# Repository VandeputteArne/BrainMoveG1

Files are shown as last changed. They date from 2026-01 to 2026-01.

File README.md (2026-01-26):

# BrainMoveG1

Een interactief cognitief en motorisch trainingssysteem met fysieke aanraakgevoelige gekleurde potten en boeiende browsergebaseerde spelletjes. Ontworpen voor cognitieve revalidatie, fitnesscentra en educatieve omgevingen.

## Overzicht

BrainMoveG1 combineert hardware en software om een boeiende trainingservaring te creëren:

- **4 Gekleurde Aanraakpotten** - Fysieke apparaten (rood, blauw, geel, groen) met nabijheidssensoren
- **Centrale Hub** - Raspberry Pi 5 die de webapplicatie draait
- **5 Trainingsspellen** - Gericht op reactiesnelheid, geheugen en hand-oogcoördinatie
- **Real-time Communicatie** - MQTT voor hardware, Socket.IO voor multiplayer gaming

## Spellen

| Spel | Type | Beschrijving |
|---|---|---|
| **Color Sprint** | Reactiesnelheid | Match de weergegeven kleuren zo snel mogelijk met de fysieke potten |
| **Memory** | Geheugenreeks | Onthoud en herhaal steeds langere kleursequenties |
| **Number Match** | Cognitieve Mapping | Leer nummer-naar-kleur koppelingen en match nummers met de juiste potten |
| **Falling Colors** | Timing & Precisie | Tik op potten voordat vallende kleuren de onderkant van het scherm bereiken |
| **Color Battle** | 1v1 Multiplayer | Twee spelers racen om als eerste hun toegewezen kleuren aan te tikken |

Elk spel bevat:
- 3 moeilijkheidsgraden (Makkelijk, Gemiddeld, Moeilijk)
- Configureerbare rondes (5, 10 of 15)
- Selecteerbare kleurpotten
- Ranglijsten
- Trainingsgeschiedenis met Excel-export

## Technologie Stack

### Frontend
- **Vue 3** met TypeScript
- **Vite** build tool
- **Vue Router** voor navigatie
- **Socket.IO Client** voor real-time multiplayer
- **ApexCharts** voor datavisualisatie

### Backend
- **FastAPI** (Python)
- **SQLite3** database
- **Socket.IO Server** voor real-time communicatie
- **MQTT** (aiomqtt) voor hardwarecommunicatie
- **Uvicorn** ASGI server

### Hardware
- **Raspberry Pi 5** - Centrale server
- **ESP32 Microcontrollers** (4x) - Eén per gekleurde pot
- **VL53L0X ToF Sensoren** - Nabijheidsdetectie
- **Mosquitto** MQTT broker

## Projectstructuur

```
BrainMoveG1/
├── backend/                    # Python FastAPI backend
│   ├── src/
│   │   ├── main.py            # FastAPI applicatie entry
│   │   ├── database.py        # SQLite connectie handler
│   │   ├── models/            # Pydantic datamodellen
│   │   ├── repositories/      # Database query laag
│   │   ├── routers/           # API endpoint handlers
│   │   └── services/          # Business logic & MQTT
│   └── scripts/               # DB initialisatie scripts
│
├── frontend/                   # Vue 3 + TypeScript web app
│   ├── src/
│   │   ├── components/        # Herbruikbare Vue componenten
│   │   ├── views/             # Pagina componenten
│   │   ├── composables/       # Vue 3 composables
│   │   ├── services/          # API clients
│   │   └── router/            # Route definities
│   └── public/                # Statische bestanden
│
├── esp32/                      # Arduino firmware voor ESP32
│   └── brainmove_mqtt/        # MQTT-enabled pot firmware
│
├── hardware/                   # Hardware ontwerpbestanden
│   ├── 3d-models/             # 3D CAD bestanden voor potten
│   └── electronics/           # Schema's
│
├── docs/                       # Documentatie
│   ├── BrainMove-Installatiehandleiding.md
│   └── BrainMove-Gebruikshandleiding.md
│
└── requirements.txt            # Python dependencies
```

## Vereisten

- Raspberry Pi 5 met microSD kaart (32GB+)
- 4x ESP32 microcontrollers met VL53L0X sensoren
- USB-C voeding voor Raspberry Pi
- Python 3.11+
- Node.js 20.x
- Mosquitto MQTT broker

## Installatie

### 1. Clone de Repository

```bash
git clone https://github.com/your-org/BrainMoveG1.git
cd BrainMoveG1
```

### 2. Backend Setup

```bash
# Maak en activeer virtuele omgeving
python3 -m venv venv
source venv/bin/activate  # Linux/Mac
# of: venv\Scripts\activate  # Windows

# Installeer dependencies
pip install -r requirements.txt

# Configureer omgeving
cp .env.example .env
# Bewerk .env met je MQTT broker instellingen

# Initialiseer database
python backend/scripts/init_db.py
python backend/scripts/seed_games.py
```

### 3. Frontend Setup

```bash
cd frontend

# Installeer dependencies
npm install

# Voor ontwikkeling
npm run dev

# Voor productie build
npm run build
```

### 4. MQTT Broker Setup

```bash
# Installeer Mosquitto
sudo apt install mosquitto mosquitto-clients

# Configureer voor anonieme toegang (ontwikkeling)
sudo nano /etc/mosquitto/conf.d/brainmove.conf
# Voeg toe:
# listener 1883
# allow_anonymous true

sudo systemctl restart mosquitto
```

### 5. ESP32 Firmware

1. Open `esp32/brainmove_mqtt/brainmove_mqtt.ino` in Arduino IDE
2. Stel `DEVICE_COLOR` in op: `"rood"`, `"blauw"`, `"geel"`, of `"groen"`
3. Update WiFi-gegevens naar je netwerk
4. Flash elk ESP32 apparaat

## Applicatie Starten

### Ontwikkelmodus

```bash
# Terminal 1: Backend
source venv/bin/activate
uvicorn backend.src.main:app --host 0.0.0.0 --port 8000 --reload

# Terminal 2: Frontend
cd frontend
npm run dev
```

### Productiemodus

```bash
# Backend
uvicorn backend.src.main:app --host 0.0.0.0 --port 8000

# Frontend (serveer gebouwde bestanden)
npm install -g serve
serve -s frontend/dist -l 3000
```

### Toegangspunten

| Service | URL |
|---|-----|
| Web App | http://localhost:3000 |
| API | http://localhost:8000 |
| API Docs (Swagger) | http://localhost:8000/docs |
| MQTT Broker | localhost:1883 |

## API Documentatie

De backend biedt een RESTful API met de volgende hoofdendpoints:

- `GET /games` - Lijst van alle beschikbare spellen
- `GET /games/{id}` - Speldetails ophalen
- `POST /trainingen` - Trainingsresultaten opslaan
- `GET /trainingen` - Trainingsgeschiedenis ophalen
- `GET /leaderboard/{game_id}` - Ranglijst voor spel ophalen
- `GET /devices` - Status van verbonden apparaten

Volledige interactieve documentatie beschikbaar op `/docs` wanneer de backend draait.

## Hardware Communicatie

### MQTT Topics

| Topic | Richting | Beschrijving |
|---|---|---|
| `bm/{kleur}/detect` | Apparaat → Server | Aanraakdetectie event |
| `bm/{kleur}/battery` | Apparaat → Server | Batterijniveau rapport |
| `bm/{kleur}/status` | Apparaat → Server | Apparaatstatus update |
| `bm/{kleur}/cmd` | Server → Apparaat | Commando's naar apparaat |

Kleuren: `rood`, `blauw`, `geel`, `groen`

## Documentatie

Gedetailleerde documentatie is beschikbaar in de `docs/` map:

- **Installatiehandleiding** - Complete setup instructies voor Raspberry Pi deployment
- **Gebruikshandleiding** - Hoe de applicatie te gebruiken en spellen te spelen

## Omgevingsvariabelen

### Backend (.env)

```env
MQTT_BROKER_HOST=localhost
MQTT_BROKER_PORT=1883
MQTT_KEEPALIVE=60
MQTT_RECONNECT_INTERVAL=5
HOST_IP=10.42.0.1
```

### Frontend (.env.production)

```env
VITE_API_BASE_URL=http://10.42.0.1:8000
```

## Licentie

Dit project is gelicentieerd onder de **GNU Affero General Public License v3.0** (AGPL-3.0).

Zie [LICENSE](LICENSE) voor details.

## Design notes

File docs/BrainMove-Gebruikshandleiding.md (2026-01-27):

# BrainMoveAJM: Gebruikershandleiding

> **Voor wie is deze handleiding?** Deze handleiding is bedoeld voor dagelijks gebruik van het BrainMove systeem. Voor installatie en technische setup, zie de brainmove-installatiehandleiding.

---

## Wat is BrainMove?

BrainMove is een interactief trainingssysteem met cognitieve en motorische oefeningen. Het systeem bestaat uit:

- **4 gekleurde potjes** (rood, blauw, geel, groen) met ingebouwde sensoren
- **Een centrale hub** (Raspberry Pi) die alles verbindt
- **Een webapp** om spellen te spelen en resultaten te bekijken

---

## Systeem Opstarten

### Stap 1: Hub Inschakelen

1. **Sluit de USB-C voeding aan** op de Raspberry Pi of steek de **stekker in het stopcontact**.
2. Wacht **2 minuten** tot het systeem volledig is opgestart.
3. Het WiFi-netwerk `BrainMoveG1` wordt automatisch actief.

> **Tip:**Moest de webapp nog niet actief zijn na 2 minuten, controleer of de groene LED op de Raspberry Pi, deze knippert tijdens het opstarten en brandt constant wanneer het systeem klaar is.

### Stap 2: Potjes Activeren

1. **Druk op de knop** op elk potje om deze te activeren (wakker maken uit slaapstand).
2. Wacht **circa 3 seconden** - het potje start op uit slaapstand, als het gelukt is zal je een geluid horen.
3. Hierna biept het potje enkele keren terwijl het verbinding maakt met de hub.
4. Wanneer dit lukt hoor je een **verbindingsgeluid**.
5. Herhaal voor alle 4 de potjes (rood, blauw, geel, groen).

**Als een potje niet verbindt:**
- **Houd de knop 1,5-3 seconden ingedrukt** om te herstarten (je hoort een piepje bij 1,5s)
- Zet het potje dichter bij de hub
- Laad het potje op, mogelijk is de batterij leeg

> **Let op:** Potjes gaan automatisch in slaapstand na langdurig niet-gebruik om batterij te sparen. Druk op de knop om ze te wekken.

### Stap 3: Verbind met WiFi

**Optie A: Scan de QR-code (aanbevolen)**

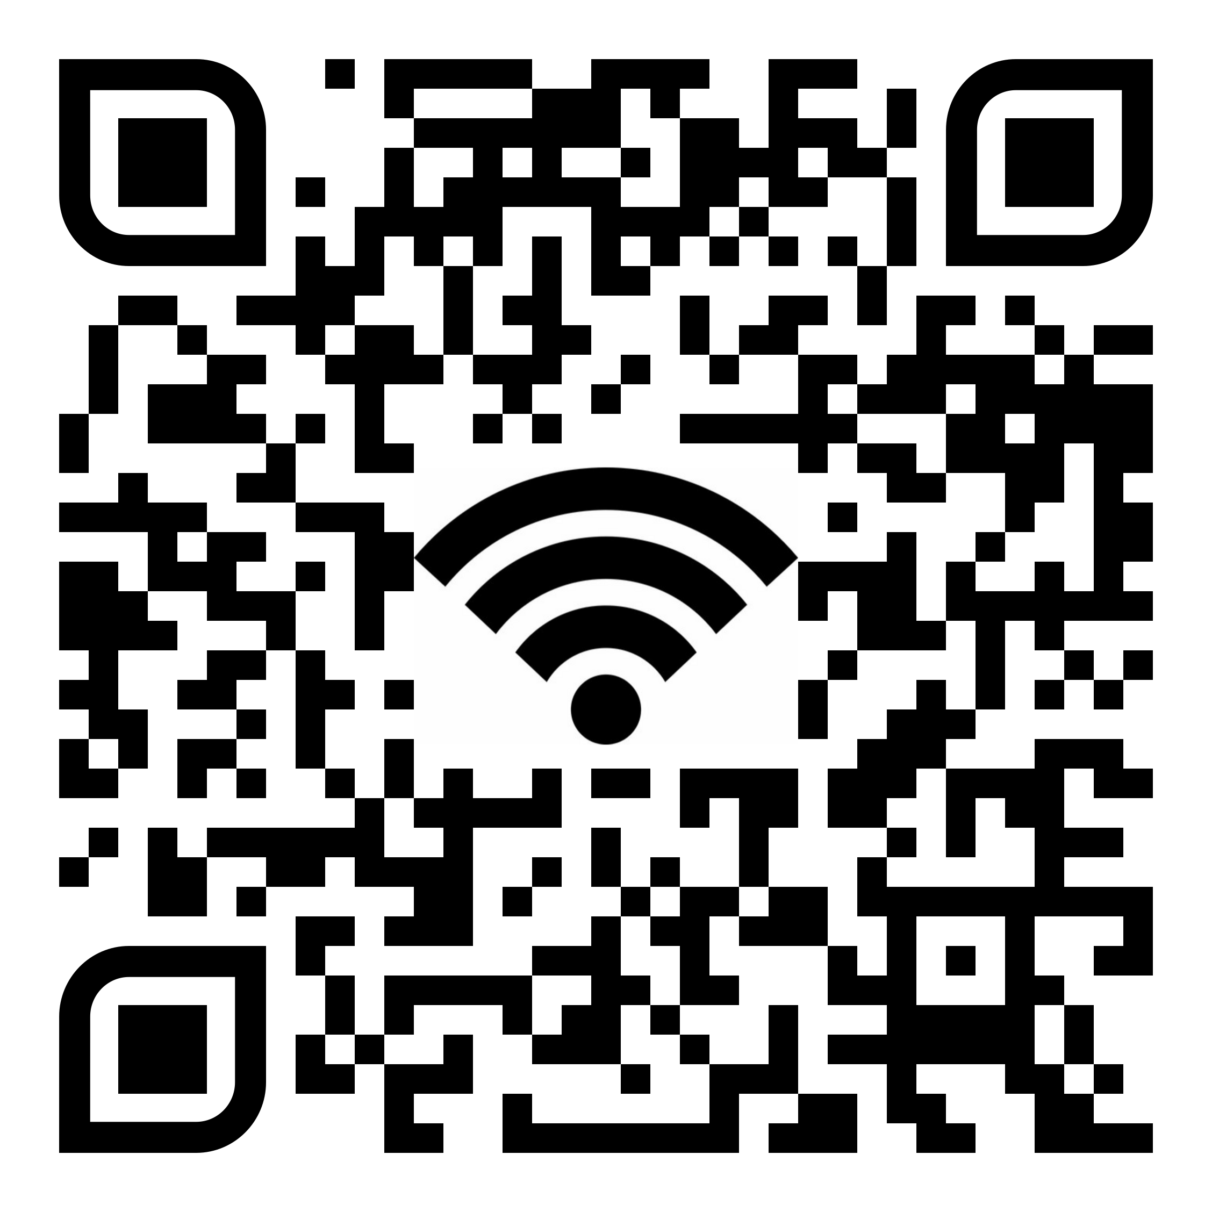
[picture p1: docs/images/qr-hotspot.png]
QR-code WiFi


Scan deze QR-code met je telefoon camera om automatisch te verbinden.

**Optie B: Handmatig verbinden**

1. Open **WiFi-instellingen** op je telefoon, tablet of laptop
2. Verbind met netwerk: **`BrainMoveG1`**
3. Voer het wachtwoord in **`bmSecure1998`**

Wacht tot je apparaat verbonden is met het WiFi-netwerk.

### Stap 4: Open de Webapp

> **iPhone gebruikers:** We raden aan om **Google Chrome** te gebruiken in plaats van Safari voor de beste ervaring met de webapp.

**Optie A: Scan de QR-code (aanbevolen)**

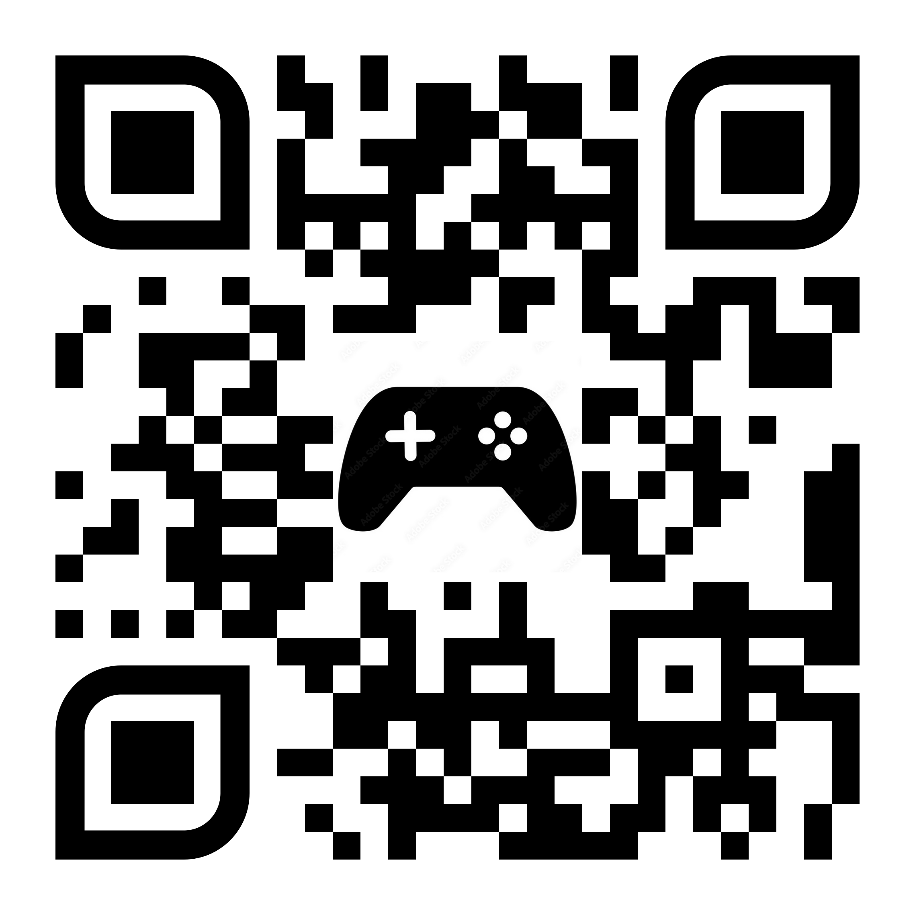
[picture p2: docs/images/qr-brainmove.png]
 

Scan deze QR-code om direct naar de webapp te gaan.

**Optie B: Handmatig openen**

1. Open een **webbrowser** (Chrome, Safari, Firefox)
2. Ga naar: **`http://10.42.0.1:3000`**

---

## Onboarding

De webapp begeleidt je door 3 schermen voordat je kunt beginnen met trainen.

### Scherm 1: Welkomstscherm

Bij het openen van de app zie je het welkomstscherm met:

- Het **BrainMove logo**
- De slogan **"Beweeg slimmer, denk scherper"**
- Een **pijl-knop** om verder te gaan

Tik op de pijl-knop om naar het volgende scherm te gaan.

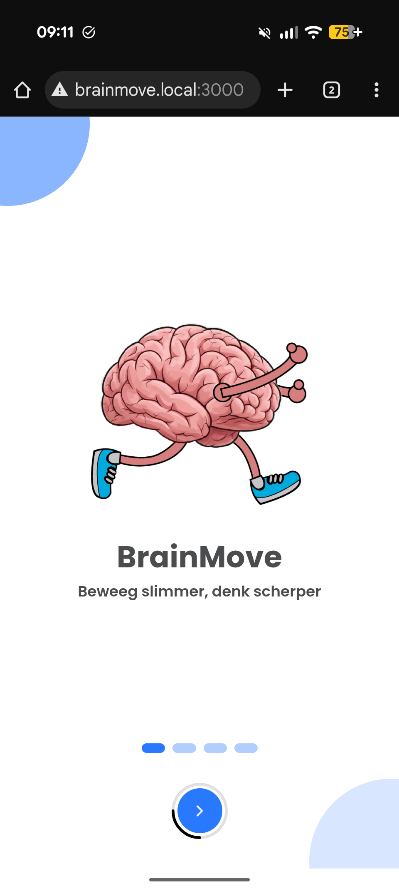
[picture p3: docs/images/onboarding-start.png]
 

### Stap 2: Potjes Op Hun Plaats Zetten

Plaats de 4 potjes in een vierkant op een vlakke ondergrond, met 2 meter tussenruimte.

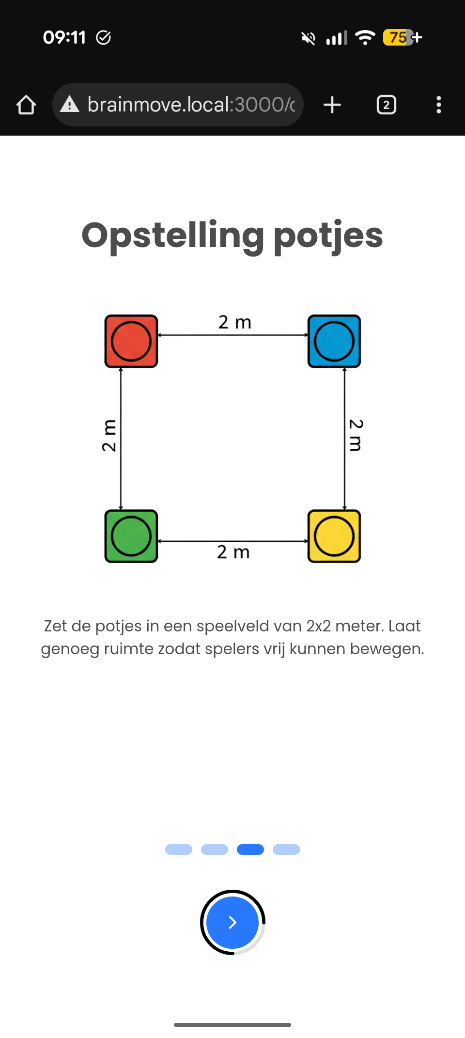
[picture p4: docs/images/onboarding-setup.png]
Kegels


**We raden deze opstelling aan voor de beste ervaring, maar als je wilt kun je de potjes ook op uw eigen manier plaatsen.**

### Scherm 3: Potjes Aanzetten (indien nog niet gedaan)

Op dit scherm zie je de 4 gekleurde potjes (rood, blauw, groen, geel) met hun verbindingsstatus.

**Wat te doen:**
1. **Druk op de groene knop** op elk potje om het aan te zetten
2. Op het scherm zie je de status veranderen van **offline** naar **online**
3. Je hoort een **geluid** wanneer een potje succesvol verbindt
4. Herhaal voor alle 4 de potjes (rood, blauw, geel, groen)

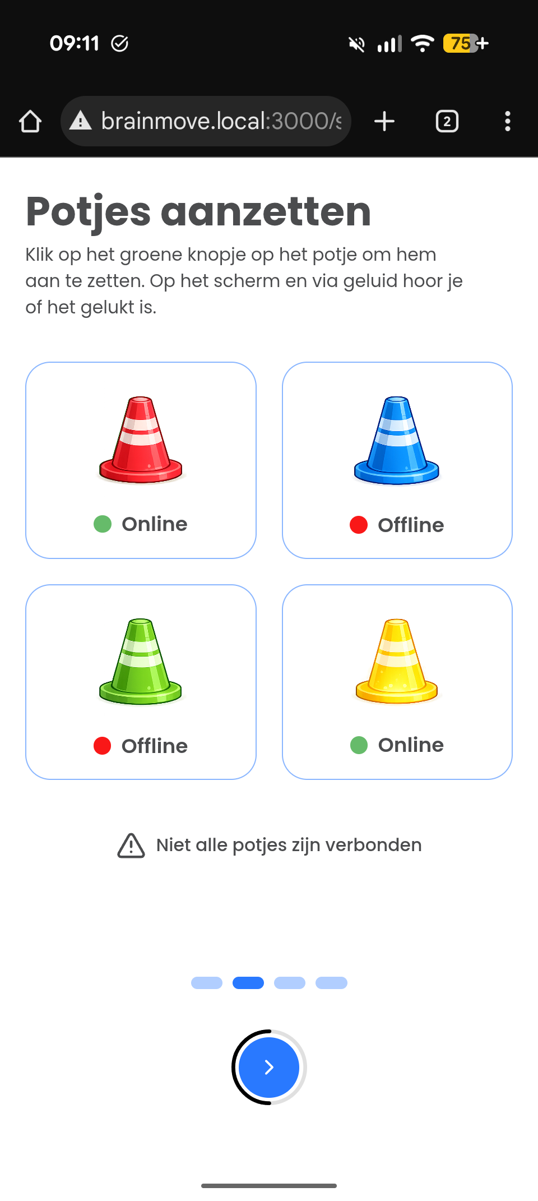
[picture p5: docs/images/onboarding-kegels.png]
 

### Scherm 4: Waarschuwing

Dit scherm toont een belangrijke waarschuwing:

> **"Schakel het systeem altijd uit via de pagina Apparaten. Trek nooit de stekker uit het stopcontact, dit kan het systeem beschadigen."**

Tik op **"Begin met trainen"** om naar het spellenvenster te gaan.

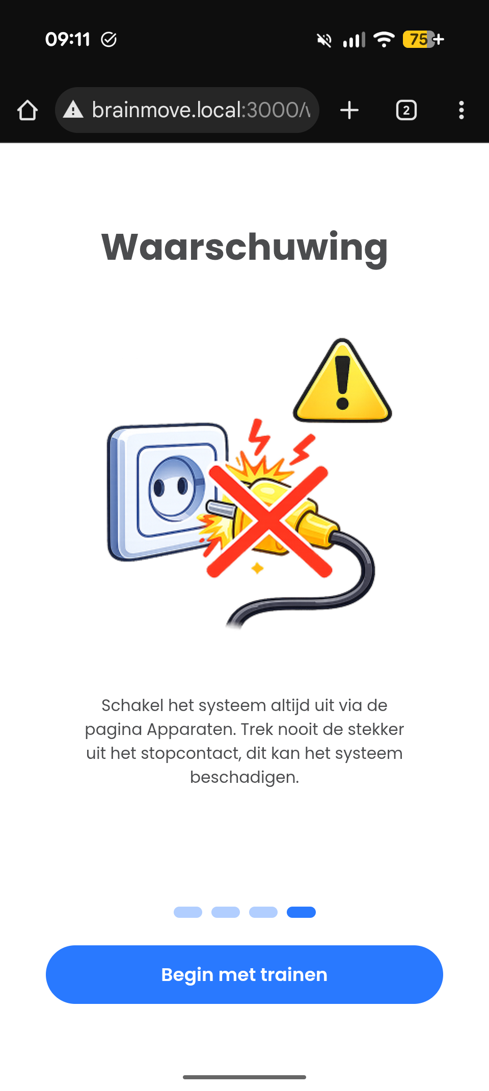
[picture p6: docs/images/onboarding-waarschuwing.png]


---

## Navigatie

Na de onboarding kom je in het hoofdmenu. Onderaan het scherm vind je de navigatiebalk met 4 opties:

| Icoon | Naam | Functie |
|---|---|---|
| Spellen | **Spellen** | Overzicht van alle beschikbare spellen |
| Klok | **Geschiedenis** | Je eerdere trainingen bekijken |
| Trofee | **Ranglijst** | Top scores van alle spelers |
| Potjes | **Apparaten** | Status van de kegels bekijken |

---

## Spellen

### Spellenvenster

In het **Spellenvenster** zie je alle 5 de spellen. Elk spel toont:
- De **naam** van het spel
- Je **hoogste score** (indien beschikbaar)
- Een **tag** met het type oefening
- Boven rechts zie je een knop om de weergave van de spellen aan te passen

Tik op een spel om naar de detailpagina te gaan.

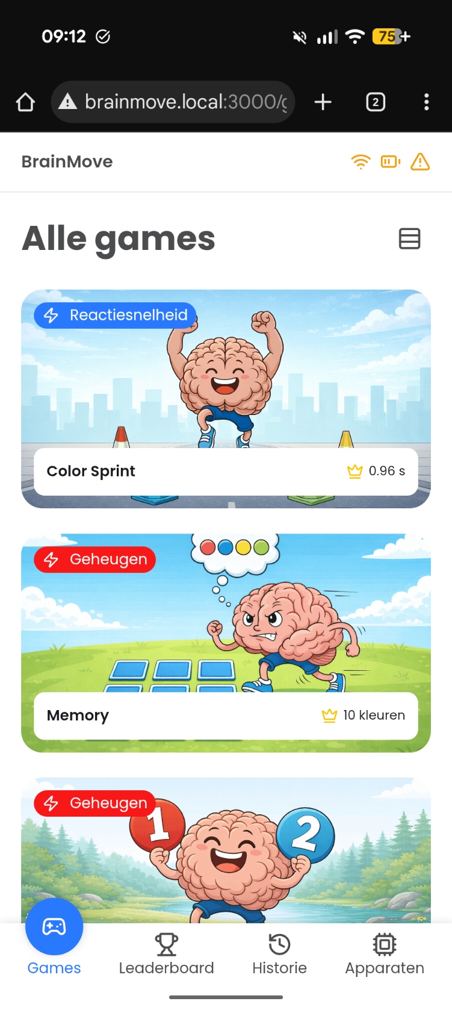
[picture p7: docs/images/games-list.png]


### Speldetails & Configuratie

Op de **detailpagina** configureer je het spel:

1. **Gebruikersnaam**: Voer je naam in (verplicht voor de ranglijst)
2. **Moeilijkheidsgraad**: Kies Makkelijk, Gemiddeld of Moeilijk
3. **Aantal rondes**: Kies het aantal rondes van de vooraf ingestelde opties
4. **Kleuren**: Selecteer welke potjes je wilt gebruiken (minimaal 2)

Er is ook een **beschrijving** van het spel en de regels.
Je ziet daar onder een **mini-ranglijst** met de top 3 spelers voor dit spel.

### Spel Starten

Tik op **"Start het spel"** om te beginnen.

> **Let op:** Je kan geen spel starten als:
> - Je geen gebruikersnaam hebt ingevuld
> - Er minder dan 2 kleuren geselecteerd zijn
> - Er minder dan 2 potjes online zijn

### Moeilijkheidsgraden

Elk spel heeft 3 moeilijkheidsgraden:

| Niveau | Beschrijving |
|---|---|
| **Makkelijk** | Langzame snelheid, meer tijd om te reageren |
| **Gemiddeld** | Standaard snelheid, normale uitdaging |
| **Moeilijk** | Snelle snelheid, minimale reactietijd |

> **Tip:** Begin met "Makkelijk" om het spel te leren kennen, en verhoog de moeilijkheid naarmate je verbetert.

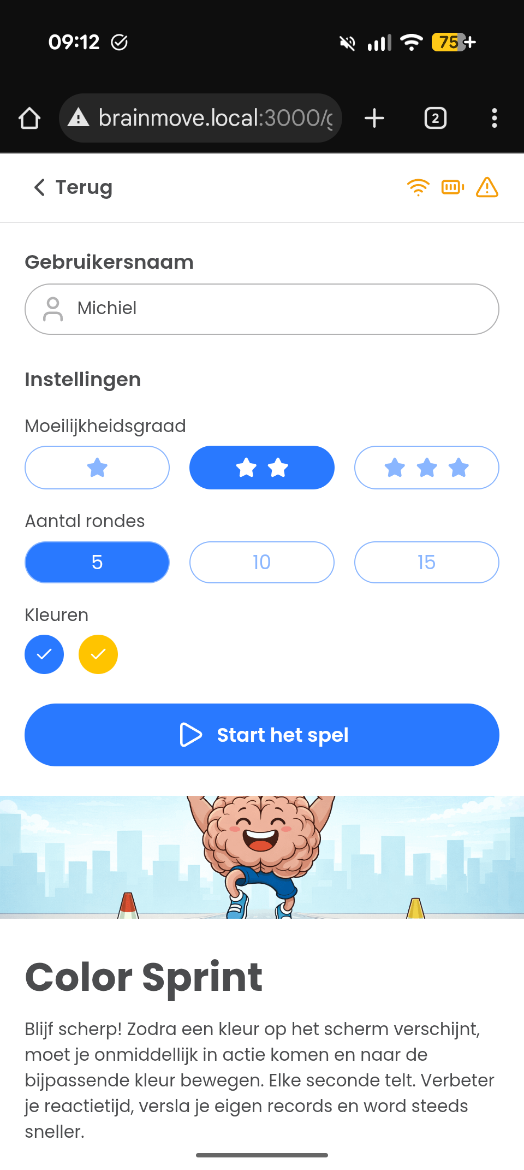
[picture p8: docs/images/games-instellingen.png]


### De 5 Spellen

BrainMove bevat 5 verschillende spellen, elk gericht op andere vaardigheden.

#### **Spel 1: Kleur Sprint (Reactiesnelheid)**

**Doel:** Tik zo snel mogelijk op het potje met de getoonde kleur.

**Hoe werkt het:**
1. Een kleur verschijnt op het scherm
2. Tik op het potje met die kleur
3. Je reactietijd wordt gemeten
4. Na de laatste ronde zie je je resultaten

**Score:** Gemiddelde reactietijd (lager = beter)

#### **Spel 2: Geheugen (Onthouden)**

**Doel:** Onthoud en herhaal steeds langere kleurenreeksen.

**Hoe werkt het:**
1. Het systeem toont een reeks kleuren op het scherm
2. Wacht tot alle kleuren zijn getoond
3. Tik de potjes aan **in dezelfde volgorde**
4. Elke ronde wordt de reeks 1 kleur langer
5. Bij een fout eindigt het spel

**Score:** Hoogste niveau bereikt + gemiddelde reactietijd

#### **Spel 3: Nummer Match (Cognitief)**

**Doel:** Koppel nummers aan kleuren en tik het juiste potje aan.

**Hoe werkt het:**
1. Je ziet een nummer-kleur mapping (bijv. 1=Rood, 2=Blauw, etc.)
2. Een nummer verschijnt op het scherm
3. Tik op het potje met de bijbehorende kleur

**Score:** Gemiddelde reactietijd + nauwkeurigheid

#### **Spel 4: Vallende Kleuren (Precisie)**

**Doel:** Tik op de kleur voordat deze "valt" naar de onderkant.

**Hoe werkt het:**
1. Een kleur verschijnt bovenaan het scherm en "valt" naar beneden
2. Tik op het juiste potje voordat de kleur de onderkant bereikt
3. Tik je op het verkeerde potje? Game over!
4. Mis je de kleur? Game over!

**Score:** Aantal succesvol gevangen kleuren

#### **Spel 5: Color Battle (2 Spelers)**

**Doel:** Versla je tegenstander door sneller te reageren op jouw kleur.

**Hoe werkt het:**
1. Twee spelers spelen tegen elkaar
2. Elke ronde krijgt elke speler een **andere kleur** te zien
3. Race om als eerste jouw kleur aan te tikken
4. De snelste speler wint de ronde
5. Na alle rondes wint de speler met de meeste gewonnen rondes

**Score:** Aantal gewonnen rondes (bij gelijkstand telt de totale reactietijd)

### Na het Spel

Na afloop van het spel zie je:

1. **Proficiat-scherm**: Felicitatie met confetti!
2. Tik op **"Bekijk je resultaten"** voor gedetailleerde statistieken

### Resultaten

Na afloop van een spel zie je het **Proficiat-scherm** met confetti. Tik op **"Bekijk je resultaten"** om je statistieken te zien:

- **Gemiddelde reactietijd** (in seconden)
- **Aantal correcte/foute antwoorden**
- **Je ranking** vergeleken met andere spelers
- **Grafiek** van je prestaties per ronde

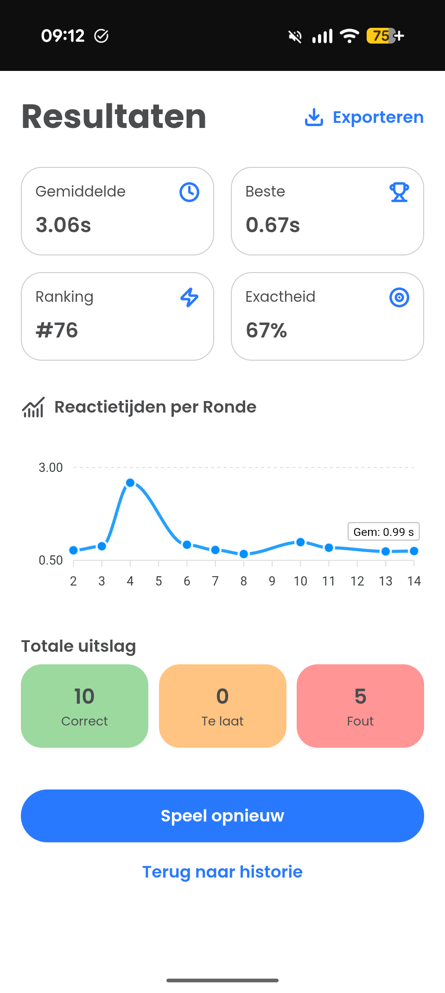
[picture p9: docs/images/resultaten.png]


---

## Geschiedenis

Bekijk al je eerdere trainingen:

1. Tik op **"Geschiedenis"** in de navigatiebalk
2. **Filter** op spel, datum of spelersnaam
3. Tik op een training voor gedetailleerde statistieken
4. **Exporteer** naar Excel voor verdere analyse

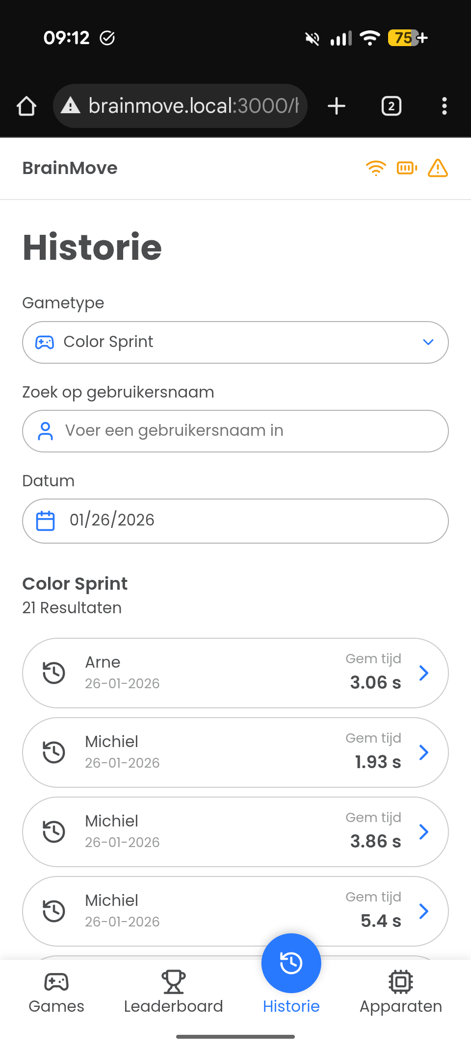
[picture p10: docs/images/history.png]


---

## Ranglijst (Leaderboard)

Vergelijk je scores met andere spelers:

1. Tik op **"Ranglijst (Leaderboard)"** in de navigatiebalk
2. Selecteer een **spel**
3. Filter op **moeilijkheidsgraad**
4. Bekijk de **Top 10** spelers

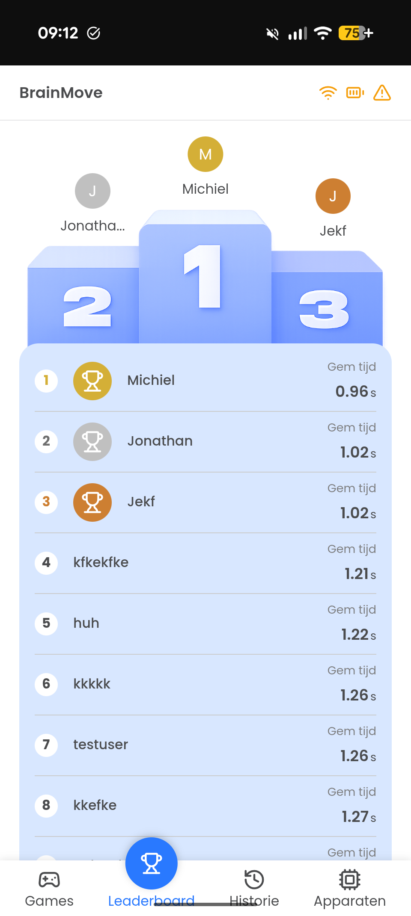
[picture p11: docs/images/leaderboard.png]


---

## Apparaten

### Status Controleren

Tik op **"Apparaten"** in de navigatiebalk om te zien:

- **Online/Offline status** van elk potje
- **Batterijpercentage** per potje
- **Laatst gezien** tijdstamp

### Status Indicatoren

| Indicator | Betekenis |
|---|---|
| Groen | Potje is online en klaar |
| Rood | Potje is offline of niet verbonden |
| Batterij-icoon | Toont het batterijpercentage |

### Potjes Uitschakelen

Om alle potjes en de Raspberry uit te schakelen (bijv. aan het einde van de dag):

1. Ga naar **"Apparaten"**
2. Tik op **"Alles uitschakelen"**
3. Voer het **beheerderswachtwoord** in **`debestebrainmove`**
4. Alle potjes gaan in slaapstand

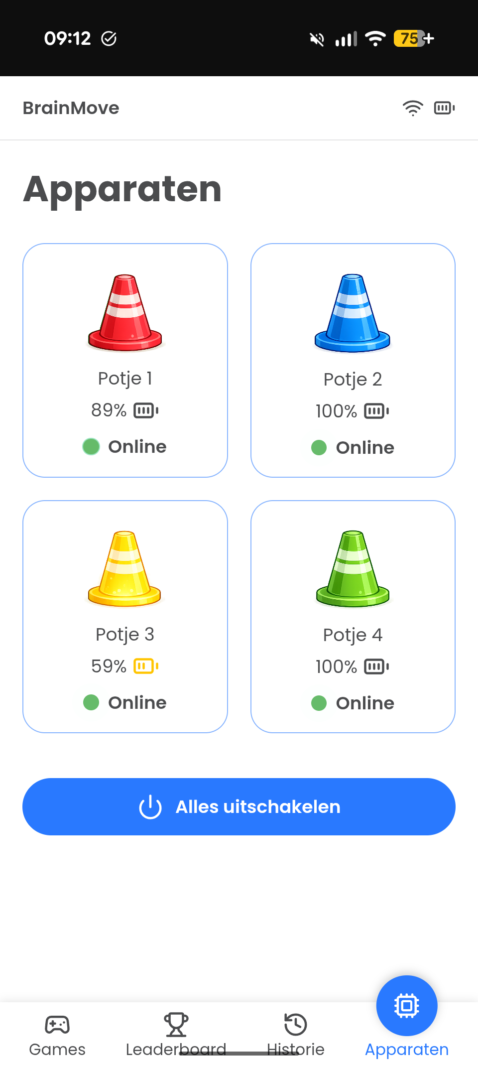
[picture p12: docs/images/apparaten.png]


---

## Problemen Oplossen

### Potje Verbindt Niet

**Symptoom:** Potje maakt geen verbindingsgeluid, blijft offline in de app.

**Oplossingen:**
1. **Houd de knop 1,5-3 seconden ingedrukt** om te herstarten (je hoort een piepje bij 1,5s, laat dan los)
2. Controleer of het potje **opgeladen** is (laad eventueel op)
3. Breng het potje **dichter bij de hub**
4. Wacht 30 seconden en probeer opnieuw

### Lage Batterij Waarschuwing

**Symptoom:** Pop-up melding over lage batterij.

**Oplossingen:**
1. **Laad het potje op** met de USB-kabel
2. Een volle oplading duurt ongeveer 2 uur

### Webapp Laadt Niet

**Symptoom:** Pagina laadt niet of geeft foutmelding.

**Oplossingen:**
1. Controleer of je verbonden bent met **WiFi "BrainMoveG1"**
2. Ververs de pagina (pull-to-refresh of F5)
3. Probeer het **IP-adres** direct: `http://10.42.0.1:3000`
4. Wis de browser cache en probeer opnieuw
5. Controleer of de hub is ingeschakeld

### Spel Reageert Niet op Aanraking

**Symptoom:** Je tikt op een potje maar er gebeurt niets.

**Oplossingen:**
1. Controleer of het potje **online** is in het apparatenmenu
2. Tik op het **midden** van het potje (waar de sensor zit)
3. Houd je hand niet te lang boven het potje (kort tikken)
4. Controleer of het spel daadwerkelijk is **gestart**
5. Herstart het potje door de knop **1,5-3 seconden ingedrukt** te houden

### Hub Start Niet Op

**Symptoom:** Geen WiFi-netwerk zichtbaar na 5 minuten.

**Oplossingen:**
1. Controleer of de **voeding** correct is aangesloten
2. Controleer of het **LED-lampje** brandt op de Raspberry Pi, deze moet groen zijn
3. **Herstart de Raspberry Pi** door het witte knopje ingedrukt te houden en te wachten tot het lampje op de Raspberry Pi rood wordt. Trek de stekker eruit, en sluit opnieuw aan
4. Neem contact op met de technische beheerder

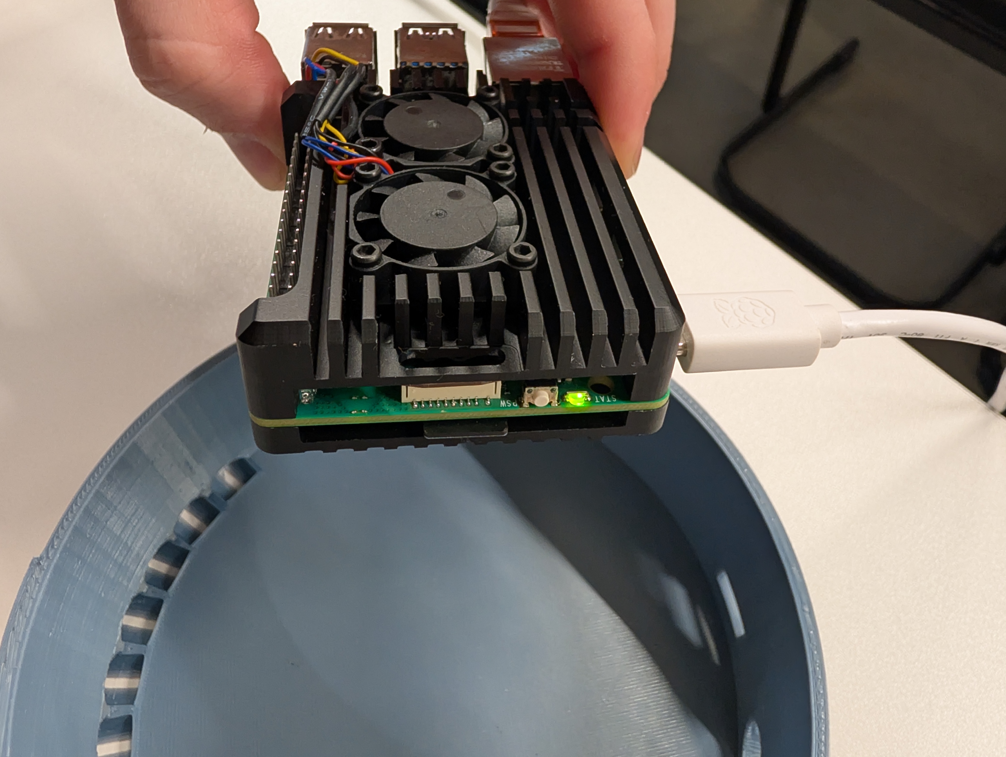
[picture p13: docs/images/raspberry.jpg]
Raspberry Pi


---

## Knopbediening Potjes

Elk potje heeft één knop met verschillende functies afhankelijk van hoe lang je drukt:

### Vanuit Slaapstand
| Actie | Resultaat |
|---|---|
| Kort drukken | Potje wordt wakker en verbindt |

> **Let op:** Na het indrukken duurt het circa **3 seconden** voordat je een geluid hoort. Dit is normaal - het potje start op uit slaapstand.

### Wanneer Actief (verbonden of verbindend)
| Indrukduur | Resultaat | Geluidssignaal |
|---|---|---|
| < 1,5 seconden | Slaapstand | Dalende toon (hoog → laag) |
| 1,5 - 3 seconden | Herstarten | Piepje bij 1,5s, dan stijgende toon |
| > 3 seconden | Geannuleerd | Lage toon |

> **Tip:** Bij het herstarten hoor je een kort piepje wanneer je de 1,5 seconden bereikt. Laat dan de knop los om te herstarten. Houd je langer dan 3 seconden vast, dan wordt de actie geannuleerd.

---

## Potjes Opladen

### Oplaadproces

1. Sluit de **USB-kabel** aan op het potje
2. Sluit de andere kant aan op een **USB-oplader** of computer
3. Het **LED-lampje** op het potje geeft de laadstatus aan:
   - **Rood**: Bezig met opladen
   - **Blauw**: Volledig opgeladen
4. Opladen duurt ongeveer **2 uur** voor een volle batterij

### Batterijduur

- Een volle batterij gaat **ongeveer 28 uur** mee bij normaal gebruik en **ongeveer 14 uur** bij intens gebruik (game na game)
- In slaapstand gaat de batterij **weken** mee
- Bij inactiviteit gaan potjes automatisch in slaapstand

> **Tip:** Laad de potjes 's avonds op zodat ze de volgende dag klaar zijn voor gebruik.

---

## Systeem Afsluiten

### Einde van de Sessie

1. Ga naar **"Apparaten"** in de app
2. Tik op **"Alles uitschakelen"** om potjes in slaapstand te zetten
3. Moest de webapp niet meer toehankelijk zijn, draai de hub open en **houd het witte knopje ingedrukt** tot de LED rood wordt
4. Ontkoppel de **voeding** van de Raspberry Pi
5. Druk op de knop van elk potje om ze in slaapstand te zetten (kort indrukken)

---

## Tips voor Optimaal Gebruik

### Voor de Training

- Controleer of alle potjes **online** zijn
- Zorg dat potjes **voldoende opgeladen** zijn (> 20%)
- Plaats potjes op een **stabiele ondergrond**
- Zorg voor **voldoende ruimte** rond de potjes

### Tijdens de Training

- Beweeg **duidelijk en tussen de 5 - 80cm** boven de potjes
- Kijk naar het scherm voor de **volgende instructie**
- Neem **pauze** indien nodig
- Begin met **makkelijk** en verhoog geleidelijk

### Na de Training

- Bekijk je **resultaten** en voortgang
- Vergelijk met de **ranglijst**
- **Exporteer** data indien nodig
- Laad potjes op indien nodig

---

## Veiligheidsinstructies

- Gebruik het systeem op een **vlakke, stabiele ondergrond**
- Zorg voor **voldoende bewegingsruimte**
- Stop direct bij **duizeligheid of ongemak**
- Laat kinderen alleen onder **toezicht** spelen
- Houd de potjes **droog** (niet geschikt voor buiten als het vochtig is)
- Gebruik alleen de **meegeleverde voeding** voor de hub

---

## Snelle Referentie

| Actie | Hoe |
|---|-----|
| Systeem starten | USB-C voeding aansluiten op hub |
| Potje wakker maken | Druk kort op de knop (vanuit slaapstand) |
| Potje in slaapstand | Druk kort op de knop (< 1,5 sec) |
| Potje herstarten | Houd knop 1,5-3 sec ingedrukt (piepje = loslaten) |
| Knopactie annuleren | Houd knop > 3 sec ingedrukt |
| Verbinden met WiFi | Netwerk "BrainMoveG1" |
| Webapp openen | `http://10.42.0.1:3000` |
| Potjes uitschakelen | Apparaten → Alles uitschakelen |
| Potje opladen | USB-kabel aansluiten |

---

## Contact & Ondersteuning

Bij technische problemen of vragen, neem contact op met:

- **Email:**
   - arne.vandeputte@student.howest.be
   - jonathan.matthys@student.howest.be
   - michiel.gekiere@student.howest.be
- **GitHub:** https://github.com/VandeputteArne/BrainMoveG1

---

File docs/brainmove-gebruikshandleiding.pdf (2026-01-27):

BrainMove-Gebruikshandleiding.md | 2026-01-27

# BrainMoveAJM: Gebruikershandleiding

Voor wie is deze handleiding? Deze handleiding is bedoeld voor dagelijks gebruik van het BrainMove systeem. Voor installatie en technische setup, zie de brainmove-installatiehandleiding.

## Wat is BrainMove?

BrainMove is een interactief trainingssysteem met cognitieve en motorische oefeningen. Het systeem bestaat uit:

### 4 gekleurde potjes (rood, blauw, geel, groen) met ingebouwde sensoren

Een centrale hub (Raspberry Pi) die alles verbindt
Een webapp om spellen te spelen en resultaten te bekijken

## Systeem Opstarten

Stap 1: Hub Inschakelen

1. Sluit de USB-C voeding aan op de Raspberry Pi of steek de stekker in het stopcontact.
2. Wacht 2 minuten tot het systeem volledig is opgestart.
3. Het WiFi-netwerk BrainMoveG1 wordt automatisch actief.

**Tip:**Moest de webapp nog niet actief zijn na 2 minuten, controleer of de groene LED op de Raspberry Pi, deze knippert tijdens het opstarten en brandt constant wanneer het systeem klaar is.
Stap 2: Potjes Activeren
1. Druk op de knop op elk potje om deze te activeren (wakker maken uit slaapstand).
2. Wacht circa 3 seconden - het potje start op uit slaapstand, als het gelukt is zal je een geluid horen.
3. Hierna biept het potje enkele keren terwijl het verbinding maakt met de hub.
4. Wanneer dit lukt hoor je een verbindingsgeluid.
5. Herhaal voor alle 4 de potjes (rood, blauw, geel, groen).

Als een potje niet verbindt:

Houd de knop 1,5-3 seconden ingedrukt om te herstarten (je hoort een piepje bij 1,5s)
Zet het potje dichter bij de hub
Laad het potje op, mogelijk is de batterij leeg

Let op: Potjes gaan automatisch in slaapstand na langdurig niet-gebruik om batterij te sparen. Druk op de knop om ze te wekken.
Stap 3: Verbind met WiFi

Optie A: Scan de QR-code (aanbevolen)

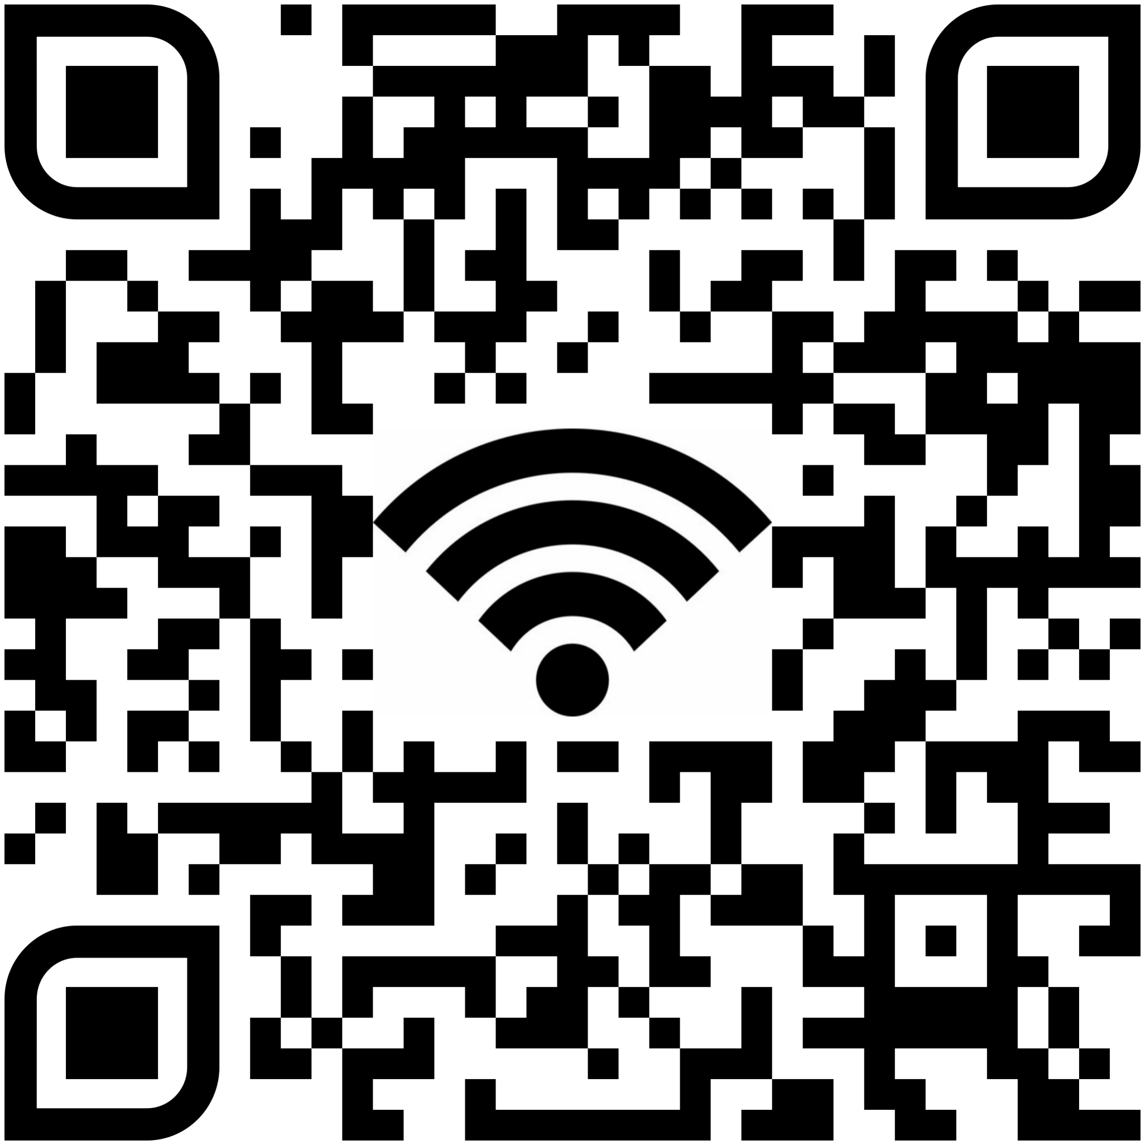
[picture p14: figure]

Scan deze QR-code met je telefoon camera om automatisch te verbinden.

Optie B: Handmatig verbinden

1. Open WiFi-instellingen op je telefoon, tablet of laptop
2. Verbind met netwerk: BrainMoveG1
3. Voer het wachtwoord in bmSecure1998

Wacht tot je apparaat verbonden is met het WiFi-netwerk.
Stap 4: Open de Webapp

Optie A: Scan de QR-code (aanbevolen)

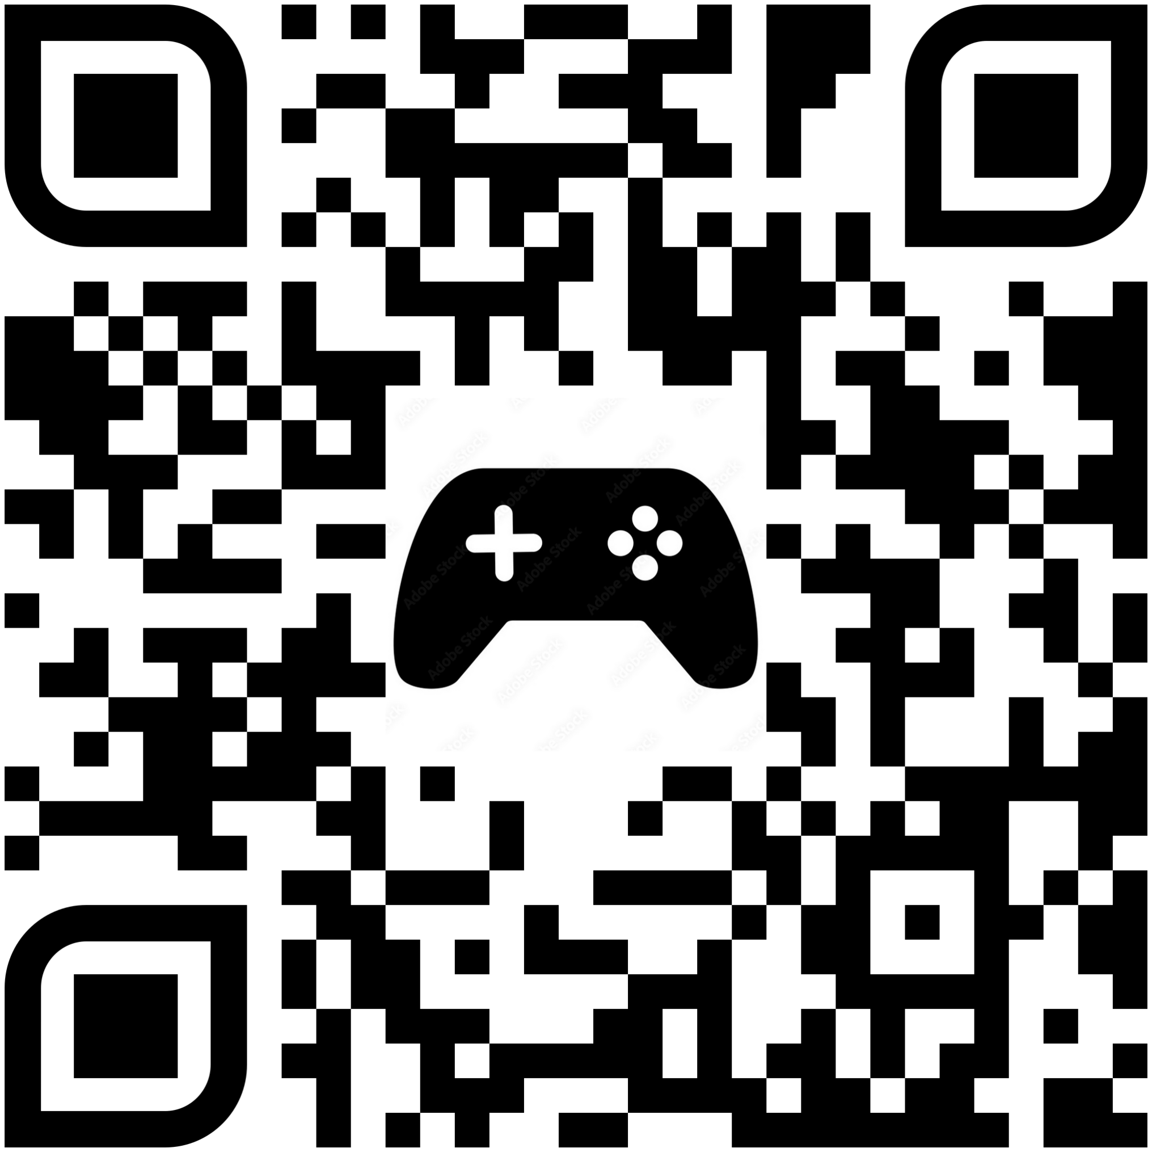
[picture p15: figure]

Scan deze QR-code om direct naar de webapp te gaan.

Optie B: Handmatig openen

1. Open een webbrowser (Chrome, Safari, Firefox)
2. Ga naar: http://brainmove.local:3000

## Onboarding

De webapp begeleidt je door 3 schermen voordat je kunt beginnen met trainen.
Scherm 1: Welkomstscherm

Bij het openen van de app zie je het welkomstscherm met:

Het BrainMove logo
De slogan "Beweeg slimmer, denk scherper" Een pijl-knop om verder te gaan

Tik op de pijl-knop om naar het volgende scherm te gaan.


Stap 2: Potjes Op Hun Plaats Zetten

Plaats de 4 potjes in een vierkant op een vlakke ondergrond, met 2 meter tussenruimte.

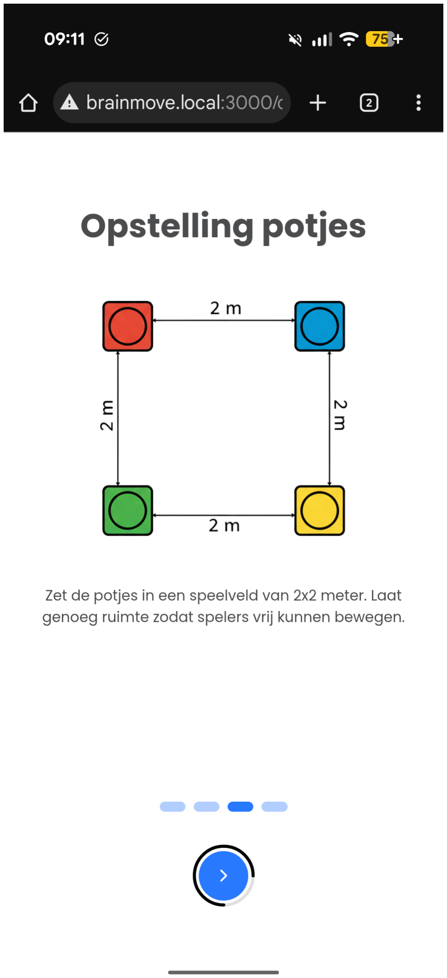
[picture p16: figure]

We raden deze opstelling aan voor de beste ervaring, maar als je wilt kun je de potjes ook op uw eigen manier plaatsen.
Scherm 3: Potjes Aanzetten (indien nog niet gedaan)

Op dit scherm zie je de 4 gekleurde potjes (rood, blauw, groen, geel) met hun verbindingsstatus.

Wat te doen:

1. Druk op de groene knop op elk potje om het aan te zetten
2. Op het scherm zie je de status veranderen van offline naar online
3. Je hoort een geluid wanneer een potje succesvol verbindt
4. Herhaal voor alle 4 de potjes (rood, blauw, geel, groen)


Scherm 4: Waarschuwing

Dit scherm toont een belangrijke waarschuwing:

"Schakel het systeem altijd uit via de pagina Apparaten. Trek nooit de stekker uit het stopcontact, dit kan het systeem beschadigen."

Tik op "Begin met trainen" om naar het spellenvenster te gaan.

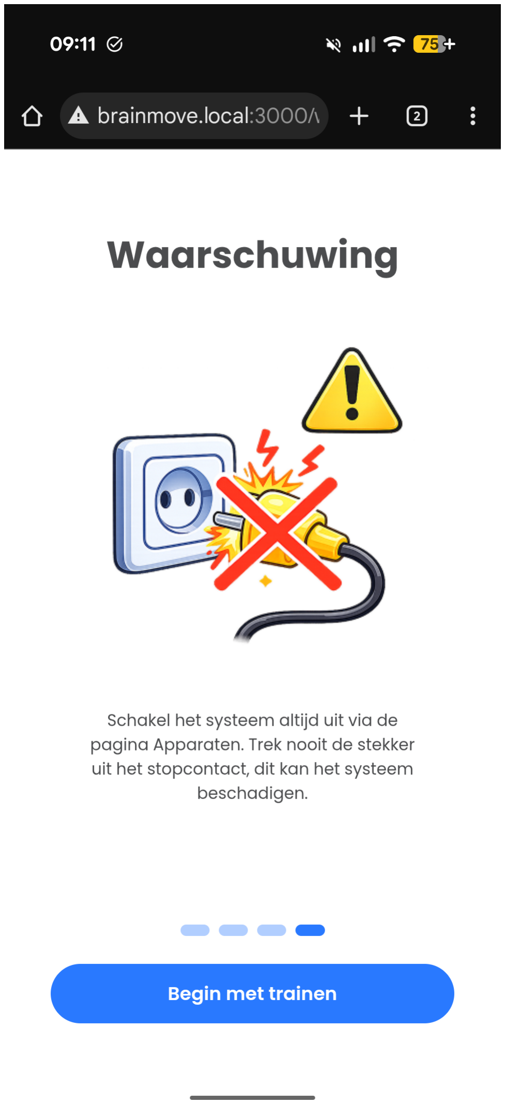
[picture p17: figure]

## Navigatie

Na de onboarding kom je in het hoofdmenu. Onderaan het scherm vind je de navigatiebalk met 4 opties:

Icoon | Naam | Functie
Spellen Spellen | Overzicht van alle beschikbare spellen
Klok | Geschiedenis Je eerdere trainingen bekijken
Trofee | Ranglijst | Top scores van alle spelers
Potjes | Apparaten | Status van de kegels bekijken

## Spellen

Spellenvenster

In het Spellenvenster zie je alle 5 de spellen. Elk spel toont:

De naam van het spel
Je hoogste score (indien beschikbaar)

Een tag met het type oefening
Boven rechts zie je een knop om de weergave van de spellen aan te passen

Tik op een spel om naar de detailpagina te gaan.


Speldetails & Configuratie

Op de detailpagina configureer je het spel:

1. Gebruikersnaam: Voer je naam in (verplicht voor de ranglijst)
2. Moeilijkheidsgraad: Kies Makkelijk, Gemiddeld of Moeilijk
3. Aantal rondes: Kies het aantal rondes van de vooraf ingestelde opties
4. Kleuren: Selecteer welke potjes je wilt gebruiken (minimaal 2)

Er is ook een beschrijving van het spel en de regels. Je ziet daar onder een mini-ranglijst met de top 3 spelers voor dit spel.
Spel Starten

Tik op "Start het spel" om te beginnen.

Let op: Je kan geen spel starten als:

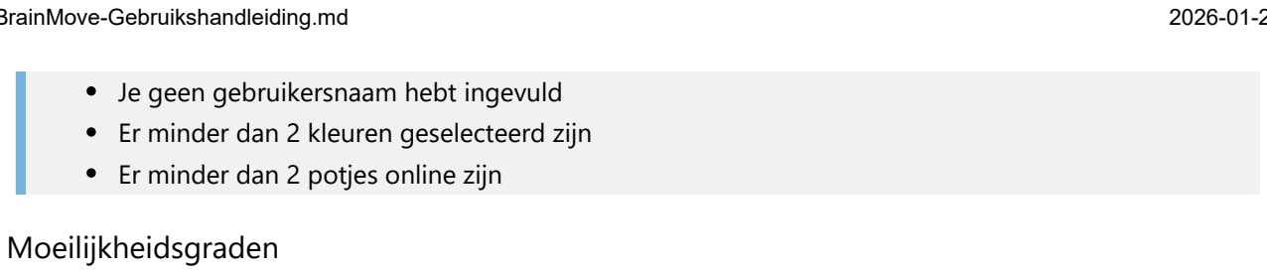
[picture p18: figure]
Je geen gebruikersnaam hebt ingevuld; Er minder dan 2 potjes online zijn; Moeilijkheidsgraden

Er minder dan 2 kleuren geselecteerd zijn

Elk spel heeft 3 moeilijkheidsgraden:

Niveau | Beschrijving
Makkelijk | Langzame snelheid, meer tijd om te reageren

Gemiddeld Standaard snelheid, normale uitdaging

Moeilijk Snelle snelheid, minimale reactietijd

Tip: Begin met "Makkelijk" om het spel te leren kennen, en verhoog de moeilijkheid naarmate je verbetert.


De 5 Spellen

BrainMove bevat 5 verschillende spellen, elk gericht op andere vaardigheden.

Spel 1: Kleur Sprint (Reactiesnelheid)

Doel: Tik zo snel mogelijk op het potje met de getoonde kleur.

Hoe werkt het:

1. Een kleur verschijnt op het scherm
2. Tik op het potje met die kleur
3. Je reactietijd wordt gemeten
4. Na de laatste ronde zie je je resultaten

Score: Gemiddelde reactietijd (lager = beter)

Spel 2: Geheugen (Onthouden)

Doel: Onthoud en herhaal steeds langere kleurenreeksen.

Hoe werkt het:

1. Het systeem toont een reeks kleuren op het scherm
2. Wacht tot alle kleuren zijn getoond
3. Tik de potjes aan in dezelfde volgorde
4. Elke ronde wordt de reeks 1 kleur langer
5. Bij een fout eindigt het spel

Score: Hoogste niveau bereikt + gemiddelde reactietijd

Spel 3: Nummer Match (Cognitief)

Doel: Koppel nummers aan kleuren en tik het juiste potje aan.

Hoe werkt het:

1. Je ziet een nummer-kleur mapping (bijv. 1=Rood, 2=Blauw, etc.)
2. Een nummer verschijnt op het scherm
3. Tik op het potje met de bijbehorende kleur

Score: Gemiddelde reactietijd + nauwkeurigheid

Spel 4: Vallende Kleuren (Precisie)

Doel: Tik op de kleur voordat deze "valt" naar de onderkant.

Hoe werkt het:

1. Een kleur verschijnt bovenaan het scherm en "valt" naar beneden
2. Tik op het juiste potje voordat de kleur de onderkant bereikt
3. Tik je op het verkeerde potje? Game over!
4. Mis je de kleur? Game over!

Score: Aantal succesvol gevangen kleuren

Spel 5: Color Battle (2 Spelers)

Doel: Versla je tegenstander door sneller te reageren op jouw kleur.

Hoe werkt het:

1. Twee spelers spelen tegen elkaar
2. Elke ronde krijgt elke speler een andere kleur te zien
3. Race om als eerste jouw kleur aan te tikken
4. De snelste speler wint de ronde
5. Na alle rondes wint de speler met de meeste gewonnen rondes

Score: Aantal gewonnen rondes (bij gelijkstand telt de totale reactietijd)
Na het Spel

Na afloop van het spel zie je:

1. Proficiat-scherm: Felicitatie met confetti!
2. Tik op "Bekijk je resultaten" voor gedetailleerde statistieken
Resultaten

Na afloop van een spel zie je het Proficiat-scherm met confetti. Tik op "Bekijk je resultaten" om je statistieken te zien:

Gemiddelde reactietijd (in seconden)
Aantal correcte/foute antwoorden
Je ranking vergeleken met andere spelers Grafiek van je prestaties per ronde


## Geschiedenis

Bekijk al je eerdere trainingen:

1. Tik op "Geschiedenis" in de navigatiebalk
2. Filter op spel, datum of spelersnaam
3. Tik op een training voor gedetailleerde statistieken
4. Exporteer naar Excel voor verdere analyse

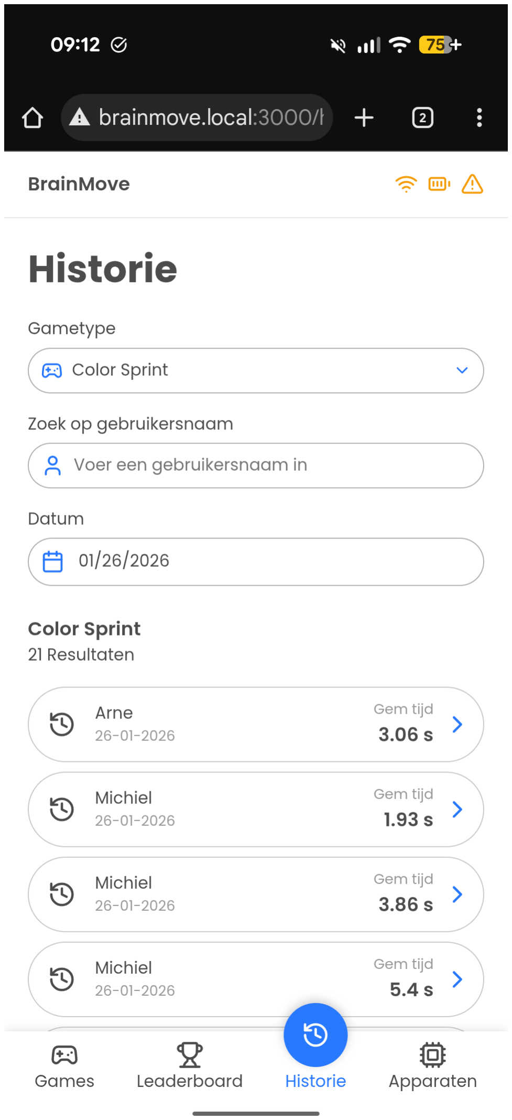
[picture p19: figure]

## Ranglijst (Leaderboard)

Vergelijk je scores met andere spelers:

1. Tik op "Ranglijst (Leaderboard)" in de navigatiebalk
2. Selecteer een spel
3. Filter op moeilijkheidsgraad
4. Bekijk de Top 10 spelers


## Apparaten

Status Controleren

Tik op "Apparaten" in de navigatiebalk om te zien:

Online/Offline status van elk potje Batterijpercentage per potje
Laatst gezien tijdstamp
Status Indicatoren
Indicator | Betekenis
Groen | Potje is online en klaar
Rood | Potje is offline of niet verbonden

Batterij-icoon Toont het batterijpercentage

Potjes Uitschakelen

Om alle potjes en de Raspberry uit te schakelen (bijv. aan het einde van de dag):

1. Ga naar "Apparaten"
2. Tik op "Alles uitschakelen"
3. Voer het beheerderswachtwoord in debestebrainmove
4. Alle potjes gaan in slaapstand

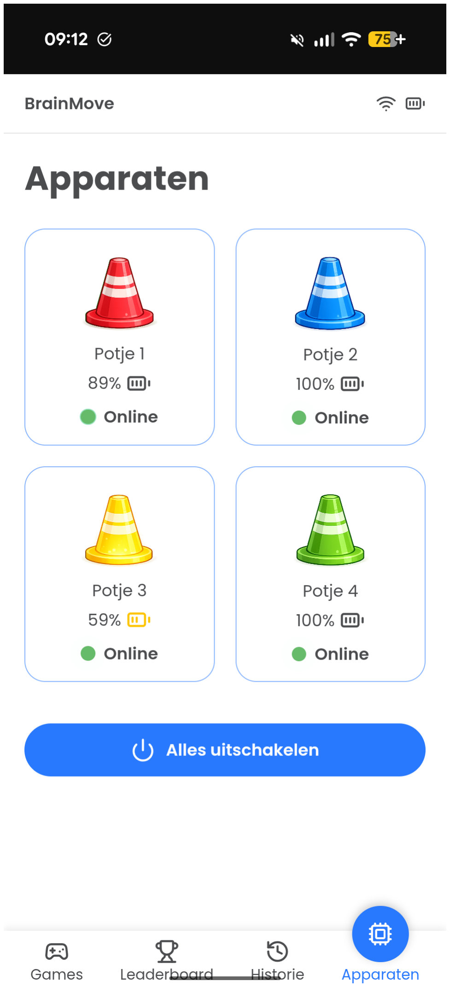
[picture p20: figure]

## Problemen Oplossen

Potje Verbindt Niet

Symptoom: Potje maakt geen verbindingsgeluid, blijft offline in de app.

Oplossingen:

1. Houd de knop 1,5-3 seconden ingedrukt om te herstarten (je hoort een piepje bij 1,5s, laat dan los)
2. Controleer of het potje opgeladen is (laad eventueel op)
3. Breng het potje dichter bij de hub
4. Wacht 30 seconden en probeer opnieuw
Lage Batterij Waarschuwing

Symptoom: Pop-up melding over lage batterij.

Oplossingen:

1. Laad het potje op met de USB-kabel
2. Een volle oplading duurt ongeveer 2 uur
Webapp Laadt Niet

Symptoom: Pagina laadt niet of geeft foutmelding.

Oplossingen:

1. Controleer of je verbonden bent met WiFi "BrainMoveG1"
2. Ververs de pagina (pull-to-refresh of F5)
3. Probeer het IP-adres direct: http://brainmove.local:3000
4. Wis de browser cache en probeer opnieuw
5. Controleer of de hub is ingeschakeld
Spel Reageert Niet op Aanraking

Symptoom: Je tikt op een potje maar er gebeurt niets.

Oplossingen:

1. Controleer of het potje online is in het apparatenmenu
2. Tik op het midden van het potje (waar de sensor zit)
3. Houd je hand niet te lang boven het potje (kort tikken)
4. Controleer of het spel daadwerkelijk is gestart
5. Herstart het potje door de knop 1,5-3 seconden ingedrukt te houden
Hub Start Niet Op

Symptoom: Geen WiFi-netwerk zichtbaar na 5 minuten.

Oplossingen:

1. Controleer of de voeding correct is aangesloten
2. Controleer of het LED-lampje brandt op de Raspberry Pi, deze moet groen zijn
3. Herstart de Raspberry Pi door het witte knopje ingedrukt te houden en te wachten tot het lampje op de Raspberry Pi rood wordt. Trek de stekker eruit, en sluit opnieuw aan
4. Neem contact op met de technische beheerder

## Knopbediening Potjes

Elk potje heeft één knop met verschillende functies afhankelijk van hoe lang je drukt:
Vanuit Slaapstand
Actie | Resultaat

Actie | Resultaat

Kort drukken Potje wordt wakker en verbindt

Let op: Na het indrukken duurt het circa 3 seconden voordat je een geluid hoort. Dit is normaal - het potje start op uit slaapstand.
Wanneer Actief (verbonden of verbindend)
Indrukduur | Resultaat | Geluidssignaal
< 1,5 seconden | Slaapstand | Dalende toon (hoog → laag)
1,5 - 3 seconden Herstarten | Piepje bij 1,5s, dan stijgende toon
> 3 seconden | Geannuleerd Lage toon

Tip: Bij het herstarten hoor je een kort piepje wanneer je de 1,5 seconden bereikt. Laat dan de knop los om te herstarten. Houd je langer dan 3 seconden vast, dan wordt de actie geannuleerd.

## Potjes Opladen

Oplaadproces

1. Sluit de USB-kabel aan op het potje
2. Sluit de andere kant aan op een USB-oplader of computer
3. Het LED-lampje op het potje geeft de laadstatus aan: Rood: Bezig met opladen
Blauw: Volledig opgeladen
4. Opladen duurt ongeveer 2 uur voor een volle batterij
Batterijduur

Een volle batterij gaat ongeveer 28 uur mee bij normaal gebruik en ongeveer 14 uur bij intens gebruik (game na game)
In slaapstand gaat de batterij weken mee
Bij inactiviteit gaan potjes automatisch in slaapstand

Tip: Laad de potjes 's avonds op zodat ze de volgende dag klaar zijn voor gebruik.

## Systeem Afsluiten

Einde van de Sessie

1. Ga naar "Apparaten" in de app
2. Tik op "Alles uitschakelen" om potjes in slaapstand te zetten
3. Moest de webapp niet meer toehankelijk zijn, draai de hub open en houd het witte knopje ingedrukt tot de LED rood wordt
4. Ontkoppel de voeding van de Raspberry Pi

5. Druk op de knop van elk potje om ze in slaapstand te zetten (kort indrukken)

## Tips voor Optimaal Gebruik

Voor de Training

Controleer of alle potjes online zijn
Zorg dat potjes voldoende opgeladen zijn (> 20%) Plaats potjes op een stabiele ondergrond
Zorg voor voldoende ruimte rond de potjes
Tijdens de Training

Beweeg duidelijk en tussen de 5 - 80cm boven de potjes Kijk naar het scherm voor de volgende instructie
Neem pauze indien nodig
Begin met makkelijk en verhoog geleidelijk
Na de Training

Bekijk je resultaten en voortgang Vergelijk met de ranglijst Exporteer data indien nodig Laad potjes op indien nodig

## Veiligheidsinstructies

Gebruik het systeem op een vlakke, stabiele ondergrond Zorg voor voldoende bewegingsruimte
Stop direct bij duizeligheid of ongemak
Laat kinderen alleen onder toezicht spelen
Houd de potjes droog (niet geschikt voor buiten als het vochtig is) Gebruik alleen de meegeleverde voeding voor de hub

## Snelle Referentie

Actie | Hoe
Systeem starten | USB-C voeding aansluiten op hub
Potje wakker maken | Druk kort op de knop (vanuit slaapstand)
Potje in slaapstand | Druk kort op de knop (< 1,5 sec)
Potje herstarten | Houd knop 1,5-3 sec ingedrukt (piepje = loslaten)

Knopactie annuleren Houd knop > 3 sec ingedrukt

Verbinden met WiFi Netwerk "BrainMoveG1"

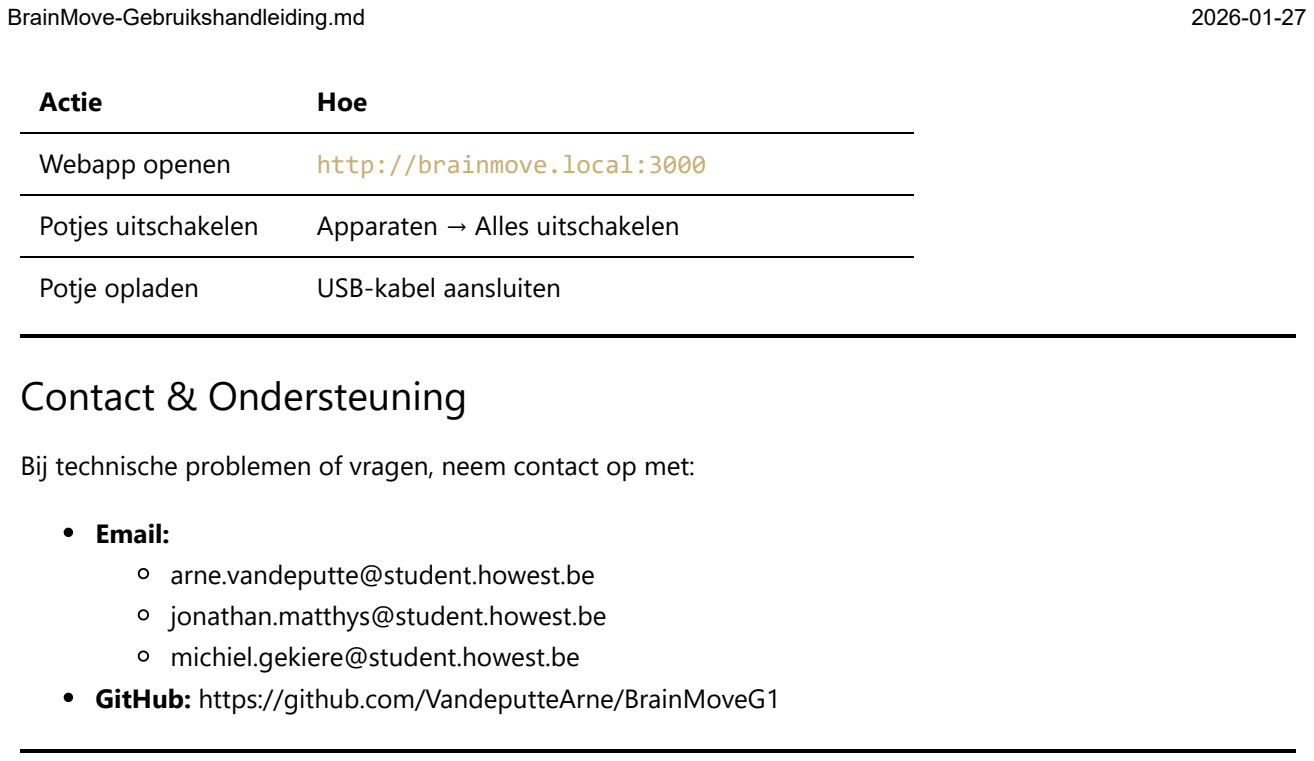
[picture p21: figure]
Actie; Hoe; Webapp openen; http://brainmove.local:3000; Potjes uitschakelen; Apparaten → Alles uitschakelen; Potje opladen; USB-kabel aansluiten; Contact & Ondersteuning; Email:; arne.vandeputte@student.howest.be jonathan.matthys@student.howest.be michiel.gekiere@student.howest.be GitHub: https://github.com/VandeputteArne/BrainMoveG1

Bij technische problemen of vragen, neem contact op met:

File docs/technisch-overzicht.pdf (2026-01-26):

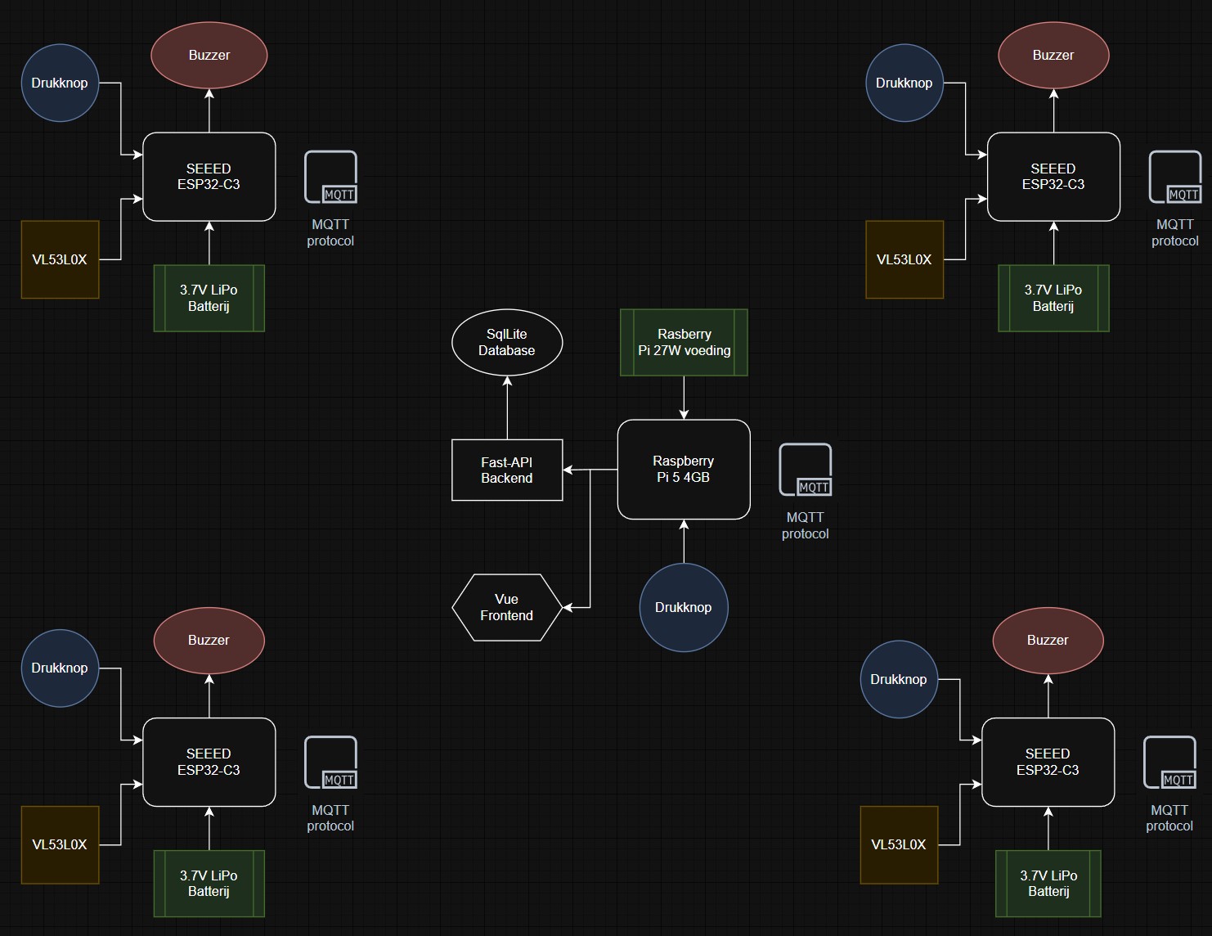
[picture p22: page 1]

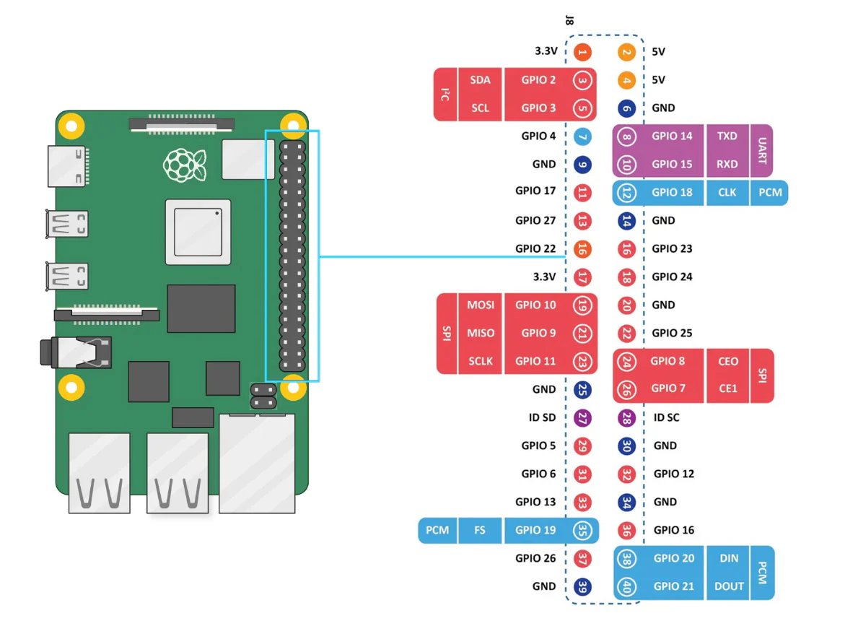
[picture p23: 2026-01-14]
hardware/electronics/rpi5-pins.png

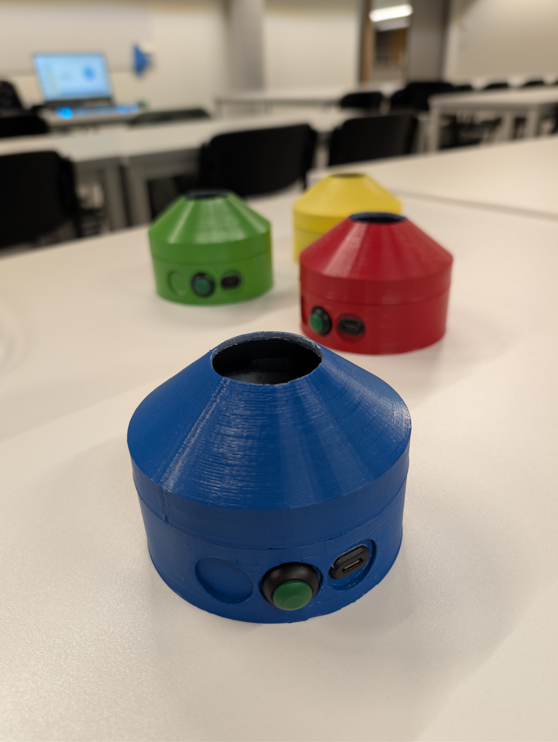
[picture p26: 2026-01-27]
docs/images/kegels.jpg

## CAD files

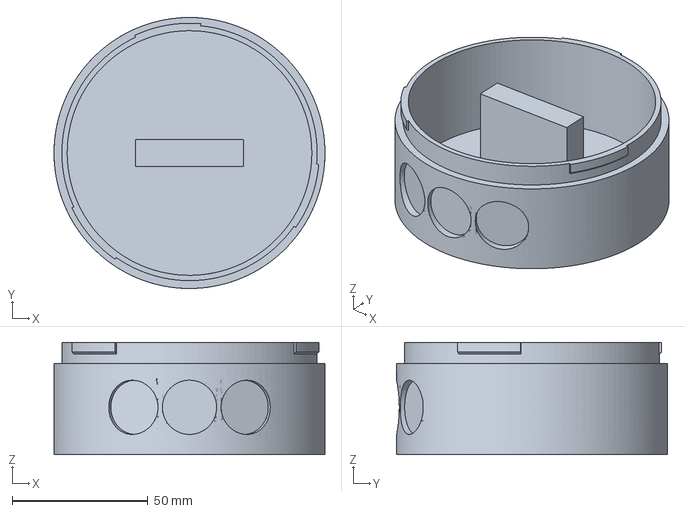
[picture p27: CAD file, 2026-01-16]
hardware/3d-models/cones/cone-base-v2 1.3mf
100.0 x 100.0 x 41.5 mm

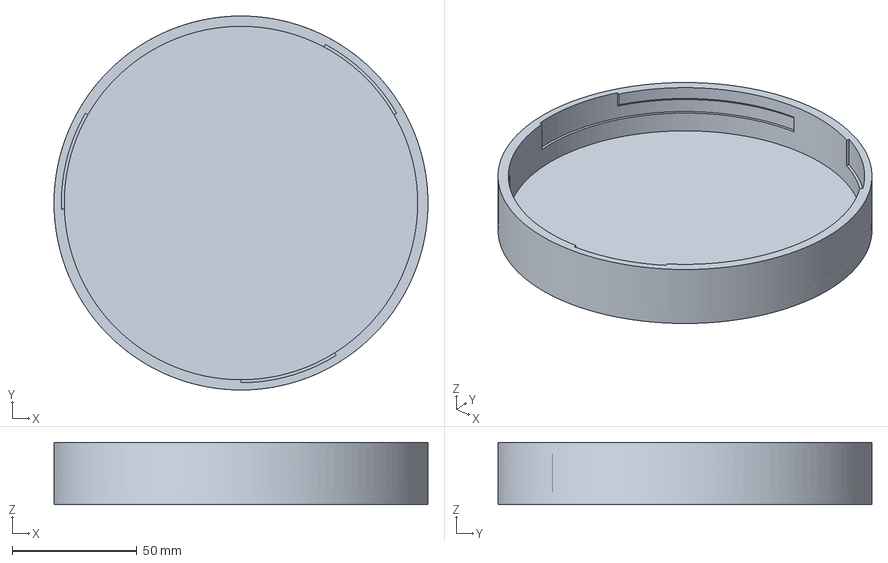
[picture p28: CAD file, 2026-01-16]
hardware/3d-models/hub/hub-top-v3.3mf
150.0 x 150.0 x 25.0 mm

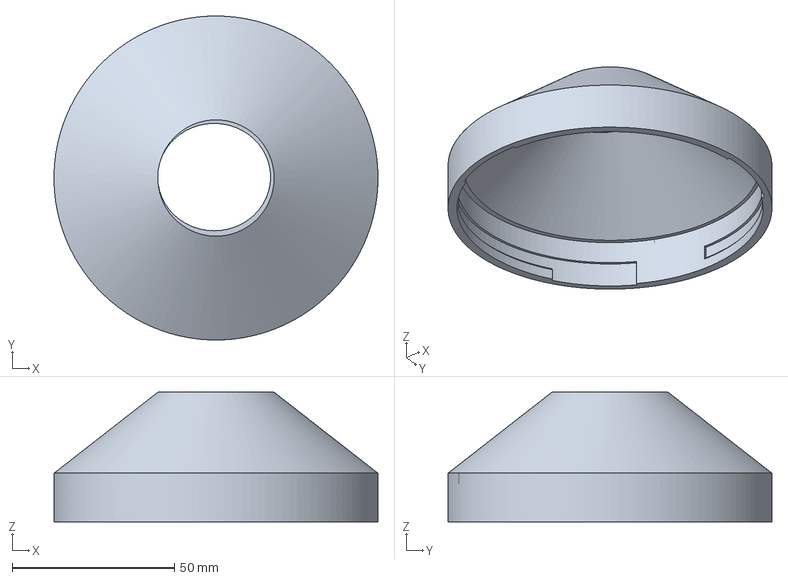
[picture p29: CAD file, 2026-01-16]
hardware/3d-models/cones/cone-top-v2 1.3mf
100.0 x 100.0 x 40.0 mm

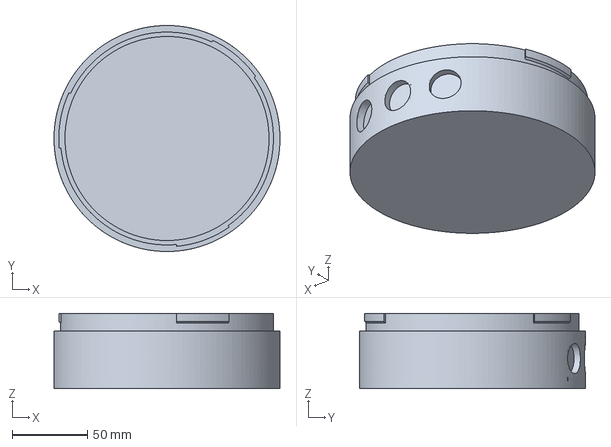
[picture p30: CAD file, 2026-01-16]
hardware/3d-models/hub/hub-base-v3.3mf
150.0 x 150.0 x 50.0 mm

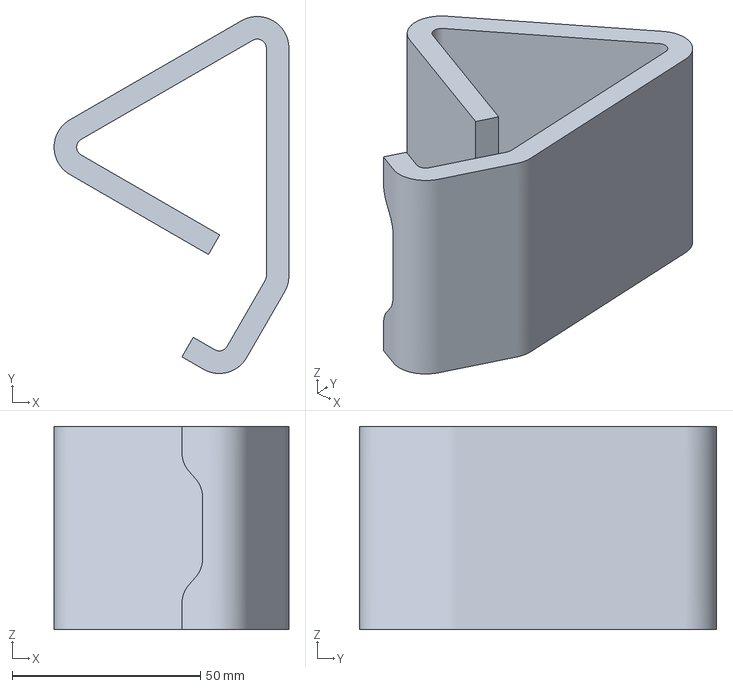
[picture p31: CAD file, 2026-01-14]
hardware/3d-models/hub/phone-holder-v2 1.3mf
62.4 x 94.9 x 54.0 mm

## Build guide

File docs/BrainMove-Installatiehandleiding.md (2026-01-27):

# BrainMoveAJM: Installatiegids

> **Snelle Start:** Wil je alle stappen overslaan? Vraag een kant-en-klare SD-kaart image aan!
> Neem contact op via arne.vandeputte@student.howest.be, jonathan.matthys@student.howest.be, michiel.gekiere@student.howest.be om de vooraf geconfigureerde RPi image te ontvangen.
> Je hoeft dan alleen de image te flashen en de ESP32's te programmeren (Fase 10).

---

**Samenvatting Project**

* **Hostnaam:** `BrainMoveAJM`
* **Gebruiker:** `bmajm`
* **Wachtwoord:** `secureajm5!`
* **OS:** Debian Trixie (via RPi Imager)
* **Netwerk:** Hotspot `10.42.0.1`, Ethernet `192.168.137.50`
* **Frontend URL:** `http://10.42.0.1:3000`
* **Backend URL:** `http://10.42.0.1:8000`
* **SSID:** `BrainMoveG1`
* **Communicatie:** MQTT (Mosquitto broker)

---

## Architectuur Overzicht

```
Client Device (Telefoon/Laptop)
    │
    ├── http://10.42.0.1:3000  ──►  Frontend (serve)
    │
    └── http://10.42.0.1:8000  ──►  Backend (uvicorn + Socket.IO)

ESP32 Devices (4x: rood, blauw, geel, groen)
    │
    └── 10.42.0.1:1883  ──►  MQTT Broker (mosquitto)
```

**Opmerking:** Deze setup gebruikt GEEN nginx. Frontend en backend worden direct benaderd op hun respectievelijke poorten voor minimale latency bij real-time Socket.IO communicatie.

---

## Fase 1: SD Kaart Flashen (Op PC)

*Doel: Het besturingssysteem correct instellen voordat we de Pi aanraken.*

1. Download en installeer **Raspberry Pi Imager** op je PC.
2. Steek de MicroSD-kaart in je PC.
3. Open Imager en kies:
   * **Device:** Raspberry Pi 5.
   * **OS:** Selecteer de **Debian Trixie** image.
   * **Storage:** Selecteer je SD-kaart.

4. Klik op **Next** en kies **EDIT SETTINGS** (OS Customisation):
   * **General:**
     * Hostname: `BrainMoveAJM`
     * Username: `bmajm`
     * Password: `secureajm5!`
     * Wireless LAN: **Uitvinken** (We gebruiken eerst de kabel).

   * **Services:**
     * Vink "Enable SSH" aan -> "Use password authentication".

5. Klik op **SAVE** en **YES** om te flashen.

---

## Fase 2: Fysieke Aansluiting

*Doel: Hardware correct aansluiten. Let op de volgorde!*

1. Haal de SD-kaart uit de PC en steek deze in de Raspberry Pi.
2. Sluit de **Ethernetkabel** aan tussen de RPi en je Windows PC.
3. **⚠️ WACHT:** Sluit de stroom (USB-C) nog **niet** aan.

---

## Fase 3: Windows Netwerk Configureren (ICS)

*Doel: Internet delen van Windows naar de Pi via de kabel.*

1. Open op Windows: `ncpa.cpl` (via Windows-toets + R).
2. Rechtermuisknop op je **WiFi-adapter** (jouw internetbron) -> **Eigenschappen** -> **Delen**.
3. Vink aan: *"Andere netwerkgebruikers toestaan verbinding te maken..."*.
4. Selecteer bij "Thuisnetwerkverbinding" de **Ethernet-adapter** van de Pi.
   * *Windows geeft de ethernetpoort nu automatisch IP `192.168.137.1`.*

---

## Fase 4: Eerste Boot & Updates

*Doel: Systeem starten en basissoftware installeren.*

1. **Stroom Aan:** Sluit nu de USB-C voeding aan. Wacht 2 minuten.
2. Open PowerShell op Windows en log in:
   ```powershell
   ssh bmajm@192.168.137.50
   # Wachtwoord: secureajm5!
   ```

   *(Werkt het IP niet? Probeer `ssh bmajm@BrainMoveAJM.local`)*

3. **Statisch IP vastzetten op de Pi:**
   ```bash
   sudo nmcli con mod "Wired connection 1" ipv4.addresses 192.168.137.50/24 ipv4.gateway 192.168.137.1 ipv4.dns 8.8.8.8 ipv4.method manual
   sudo nmcli con down "Wired connection 1" && sudo nmcli con up "Wired connection 1"
   ```

4. **Software installeren:**
   ```bash
   # Update pakketlijsten
   sudo apt update && sudo apt full-upgrade -y

   # Installeer systeemtools en Python tools
   sudo apt install -y git python3-venv python3-full tree mosquitto mosquitto-clients

   # Installeer Node.js 20 (voor frontend)
   curl -fsSL https://deb.nodesource.com/setup_20.x | sudo -E bash -
   sudo apt install -y nodejs
   ```

---

## Fase 5: Mosquitto MQTT Broker Configureren

*Doel: MQTT broker instellen voor communicatie met ESP32 apparaten.*

1. **Configuratie bestand aanmaken:**
   ```bash
   sudo nano /etc/mosquitto/conf.d/brainmove.conf
   ```

2. **Plak deze inhoud:**
   ```conf
   # BrainMove MQTT Broker Configuration
   listener 1883
   allow_anonymous true
   persistence true
   persistence_location /var/lib/mosquitto/
   max_queued_messages 1000
   log_dest file /var/log/mosquitto/mosquitto.log
   connection_messages true
   ```

3. **Mosquitto herstarten en inschakelen:**
   ```bash
   sudo systemctl restart mosquitto
   sudo systemctl enable mosquitto
   ```

4. **Test de broker:**
   ```bash
   # In terminal 1: subscribe
   mosquitto_sub -h localhost -t "test/#" &

   # In terminal 2: publish
   mosquitto_pub -h localhost -t "test/hello" -m "MQTT werkt!"

   # Je zou "MQTT werkt!" moeten zien
   ```

---

## Fase 6: Project Ophalen & Hotspot

*Doel: Code downloaden en WiFi netwerk (BrainMoveG1) maken.*

1. **Clone Repository:**
   ```bash
   mkdir -p ~/BrainMove && cd ~/BrainMove
   # Vervang <URL> met de juiste repository URL
   git clone <JOUW_REPO_URL> BrainMoveG1
   ```

2. **Hotspot Instellen:**
   *Controleer met `ip link` welke interface je dongle is (meestal `wlan1` bij RPi5).*
   ```bash
   sudo raspi-config nonint do_wifi_country BE

   # Hotspot aanmaken
   sudo nmcli con add type wifi ifname wlan1 con-name "BrainMoveG1" autoconnect yes ssid "BrainMoveG1" mode ap ipv4.method shared wifi-sec.key-mgmt wpa-psk wifi-sec.psk "YOUR_SECURE_PASSWORD"

   sudo nmcli connection up "BrainMoveG1"
   ```

3. **Controleer hotspot status:**
   ```bash
   nmcli connection show --active | grep BrainMoveG1
   ```

---

## Fase 7: Backend Installatie (met venv)

*Doel: Virtuele omgeving opzetten en dependencies installeren.*

1. **Ga naar de map en maak de omgeving:**
   ```bash
   cd ~/BrainMove/BrainMoveG1
   python3 -m venv venv
   source venv/bin/activate
   ```

2. **Installeer packages:**
   ```bash
   cd backend
   pip install -r requirements.txt
   ```

3. **Zet environment variabelen:**
   ```bash
   cp .env.example .env
   ```

   De `.env` bevat:
   ```env
   # MQTT Configuration
   MQTT_BROKER_HOST=localhost
   MQTT_BROKER_PORT=1883
   MQTT_KEEPALIVE=60
   MQTT_RECONNECT_INTERVAL=5

   # Network
   HOST_IP=10.42.0.1
   ```

---

## Fase 8: Frontend Build

*Doel: Website bouwen voor productie.*

1. **Controleer API configuratie:**
   ```bash
   cat ~/BrainMove/BrainMoveG1/frontend/.env.production
   ```

   Moet bevatten:
   ```env
   VITE_API_BASE_URL=http://10.42.0.1:8000
   ```

2. **Builden:**
   ```bash
   cd ~/BrainMove/BrainMoveG1/frontend
   npm install
   npm run build
   sudo npm install -g serve
   ```

---

## Fase 9: Systemd Services (Autostart)

*Doel: Alles automatisch laten starten bij boot.*

1. **Backend Service:**
   ```bash
   sudo nano /etc/systemd/system/brainmove-backend.service
   ```

   Plak:
   ```ini
   [Unit]
   Description=BrainMove Backend
   After=network.target mosquitto.service
   Wants=mosquitto.service

   [Service]
   User=bmajm
   WorkingDirectory=/home/bmajm/BrainMove/BrainMoveG1/backend
   Environment="PYTHONPATH=/home/bmajm/BrainMove/BrainMoveG1/backend:/home/bmajm/BrainMove/BrainMoveG1/backend/src"
   ExecStart=/home/bmajm/BrainMove/BrainMoveG1/venv/bin/uvicorn src.main:app --host 0.0.0.0 --port 8000
   Restart=always
   RestartSec=5

   [Install]
   WantedBy=multi-user.target
   ```

2. **Frontend Service:**
   ```bash
   sudo nano /etc/systemd/system/brainmove-frontend.service
   ```

   Plak:
   ```ini
   [Unit]
   Description=BrainMove Frontend
   After=network.target brainmove-backend.service
   Requires=brainmove-backend.service

   [Service]
   User=bmajm
   WorkingDirectory=/home/bmajm/BrainMove/BrainMoveG1/frontend
   ExecStart=/usr/bin/npx serve -s dist -l 3000
   Restart=always
   RestartSec=10

   [Install]
   WantedBy=multi-user.target
   ```

3. **Services activeren en starten:**
   ```bash
   sudo systemctl daemon-reload
   sudo systemctl enable mosquitto brainmove-backend.service brainmove-frontend.service
   sudo systemctl start brainmove-backend.service brainmove-frontend.service
   ```

4. **Status controleren:**
   ```bash
   sudo systemctl status brainmove-backend.service
   sudo systemctl status brainmove-frontend.service
   sudo systemctl status mosquitto
   ```

---

## Fase 10: ESP32 Flashen

*Doel: ESP32 apparaten programmeren met MQTT firmware.*

De ESP32 firmware staat in `esp32/brainmove_mqtt/brainmove_mqtt.ino`.

**Belangrijke instellingen in de code:**
```cpp
// WiFi credentials
const char* WIFI_SSID = "BrainMoveG1";
const char* WIFI_PASSWORD = "bmSecure5!";

// MQTT broker (Raspberry Pi)
const char* MQTT_HOST = "10.42.0.1";
const int MQTT_PORT = 1883;

// Device color (uniek per ESP32)
const char* DEVICE_COLOR = "rood";  // of: blauw, geel, groen
```

**Flash instructies:**
1. Open Arduino IDE of PlatformIO
2. Selecteer ESP32 board
3. Pas `DEVICE_COLOR` aan voor elke ESP32
4. Upload de sketch

---

## Gebruikers Toegang (QR Codes)

Print deze twee QR-codes uit voor op het apparaat:

1. **Sticker 1: "Verbind met WiFi"**
   * Code: `WIFI:T:WPA;S:BrainMoveG1;P:bmSecure5!;;`

2. **Sticker 2: "Speel het spel"**
   * Code: `http://10.42.0.1:3000`

---

## Troubleshooting

### Backend start niet
```bash
# Bekijk logs
sudo journalctl -u brainmove-backend.service -f

# Test handmatig
cd ~/BrainMove/BrainMoveG1/backend
source ../venv/bin/activate
uvicorn src.main:app --host 0.0.0.0 --port 8000
```

### ESP32 verbindt niet met MQTT
```bash
# Monitor MQTT berichten
mosquitto_sub -h localhost -t "bm/#" -v

# Controleer of broker draait
sudo systemctl status mosquitto
```

### Frontend laadt niet
```bash
# Bekijk logs
sudo journalctl -u brainmove-frontend.service -f

# Test handmatig
cd ~/BrainMove/BrainMoveG1/frontend
npx serve -s dist -l 3000
```

### Hotspot werkt niet
```bash
# Status bekijken
nmcli connection show

# Hotspot herstarten
sudo nmcli connection down BrainMoveG1
sudo nmcli connection up BrainMoveG1
```

---

## Quick Reference

| Service | URL/Poort | Doel |
|---|---|---|
| Frontend | `http://10.42.0.1:3000` | Webapp |
| Backend API | `http://10.42.0.1:8000` | REST API |
| API Docs | `http://10.42.0.1:8000/docs` | Swagger documentatie |
| MQTT Broker | `10.42.0.1:1883` | ESP32 communicatie |
| Hotspot | `BrainMoveG1` | WiFi netwerk |

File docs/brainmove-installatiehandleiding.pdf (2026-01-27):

BrainMove-Installatiehandleiding.md | 2026-01-27

# BrainMoveAJM: Installatiegids

Snelle Start: Wil je alle stappen overslaan? Vraag een kant-en-klare SD-kaart image aan! Neem contact op via arne.vandeputte@student.howest.be, jonathan.matthys@student.howest.be, michiel.gekiere@student.howest.be om de vooraf geconfigureerde RPi image te ontvangen. Je hoeft dan alleen de image te flashen en de ESP32's te programmeren (Fase 10).

Samenvatting Project

Hostnaam: BrainMoveAJM
Gebruiker: bmajm
Wachtwoord: secureajm5!
OS: Debian Trixie (via RPi Imager)
Netwerk: Hotspot 10.42.0.1, Ethernet 192.168.137.50 Frontend URL: http://brainmove.local:3000 Backend URL: http://brainmove.local:8000
SSID: BrainMoveG1
Communicatie: MQTT (Mosquitto broker)

## Architectuur Overzicht

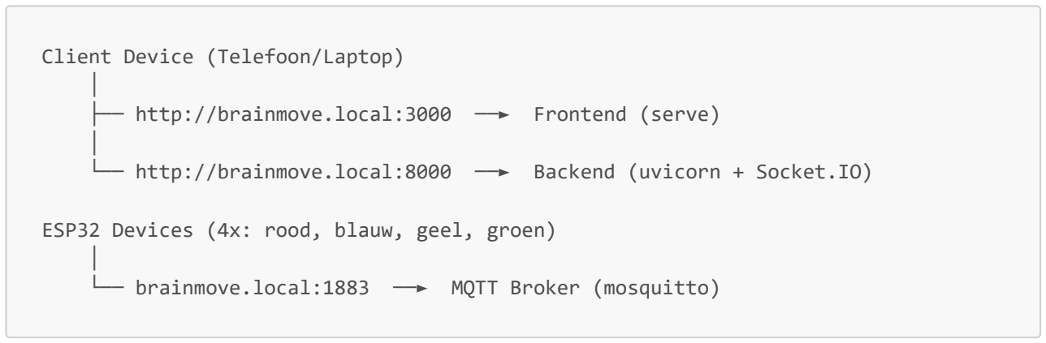
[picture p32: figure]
Client Device (Telefoon/Laptop) │ ├── http://brainmove.local:3000 ──► Frontend (serve) │

└── http://brainmove.local:8000 ──► Backend (uvicorn + Socket.IO)

ESP32 Devices (4x: rood, blauw, geel, groen)

└── brainmove.local:1883 ──► MQTT Broker (mosquitto)

Opmerking: Deze setup gebruikt GEEN nginx. Frontend en backend worden direct benaderd op hun respectievelijke poorten voor minimale latency bij real-time Socket.IO communicatie.

## Fase 1: SD Kaart Flashen (Op PC)

Doel: Het besturingssysteem correct instellen voordat we de Pi aanraken.

1. Download en installeer Raspberry Pi Imager op je PC.
2. Steek de MicroSD-kaart in je PC.
3. Open Imager en kies:

Device: Raspberry Pi 5.

OS: Selecteer de Debian Trixie image. Storage: Selecteer je SD-kaart.

4. Klik op Next en kies EDIT SETTINGS (OS Customisation):

General:

Hostname: BrainMoveAJM
Username: bmajm
Password: secureajm5!
Wireless LAN: Uitvinken (We gebruiken eerst de kabel).

Services:

Vink "Enable SSH" aan -> "Use password authentication".

5. Klik op SAVE en YES om te flashen.

## Fase 2: Fysieke Aansluiting

Doel: Hardware correct aansluiten. Let op de volgorde!

1. Haal de SD-kaart uit de PC en steek deze in de Raspberry Pi.
2. Sluit de Ethernetkabel aan tussen de RPi en je Windows PC.
3. ⚠ WACHT: Sluit de stroom (USB-C) nog niet aan.

## Fase 3: Windows Netwerk Configureren (ICS)

Doel: Internet delen van Windows naar de Pi via de kabel.

1. Open op Windows: ncpa.cpl (via Windows-toets + R).
2. Rechtermuisknop op je WiFi-adapter (jouw internetbron) -> Eigenschappen -> Delen.
3. Vink aan: "Andere netwerkgebruikers toestaan verbinding te maken...".
4. Selecteer bij "Thuisnetwerkverbinding" de Ethernet-adapter van de Pi.
Windows geeft de ethernetpoort nu automatisch IP 192.168.137.1.

## Fase 4: Eerste Boot & Updates

Doel: Systeem starten en basissoftware installeren.

1. Stroom Aan: Sluit nu de USB-C voeding aan. Wacht 2 minuten.
2. Open PowerShell op Windows en log in:

(Werkt het IP niet? Probeer ssh bmajm@BrainMoveAJM.local)

3. Statisch IP vastzetten op de Pi:

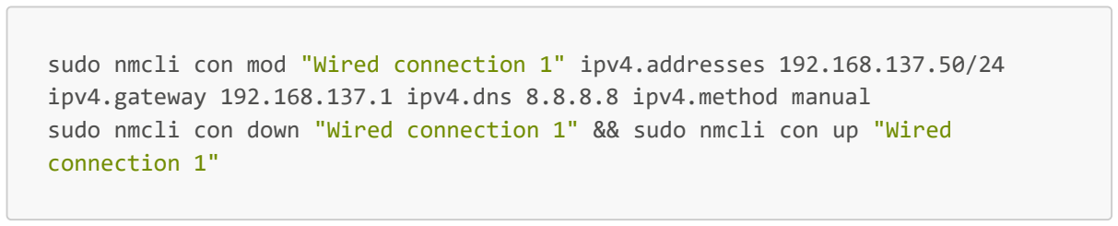
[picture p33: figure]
connection 1"

sudo nmcli con mod "Wired connection 1" ipv4.addresses 192.168.137.50/24 ipv4.gateway 192.168.137.1 ipv4.dns 8.8.8.8 ipv4.method manual
sudo nmcli con down "Wired connection 1" && sudo nmcli con up "Wired
4. Software installeren:

# Update pakketlijsten

sudo apt update && sudo apt full-upgrade -y

# Installeer systeemtools en Python tools

sudo apt install -y git python3-venv python3-full tree mosquitto mosquitto-clients

# Installeer Node.js 20 (voor frontend)

curl -fsSL https://deb.nodesource.com/setup_20.x | sudo -E bash -
sudo apt install -y nodejs

## Fase 5: Mosquitto MQTT Broker Configureren

Doel: MQTT broker instellen voor communicatie met ESP32 apparaten.

1. Configuratie bestand aanmaken:
2. Plak deze inhoud:

# BrainMove MQTT Broker Configuration listener 1883

allow_anonymous true
persistence true
persistence_location /var/lib/mosquitto/ max_queued_messages 1000
log_dest file /var/log/mosquitto/mosquitto.log connection_messages true
3. Mosquitto herstarten en inschakelen:

4. Test de broker:

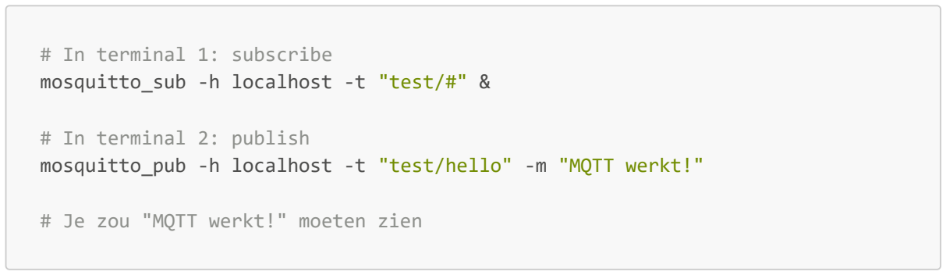
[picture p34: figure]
# In terminal 1: subscribe; # In terminal 2: publish; # Je zou "MQTT werkt!" moeten zien

mosquitto_sub -h localhost -t "test/#" &

mosquitto_pub -h localhost -t "test/hello" -m "MQTT werkt!"

## Fase 6: Project Ophalen & Hotspot

Doel: Code downloaden en WiFi netwerk (BrainMoveG1) maken.

1. Clone Repository:

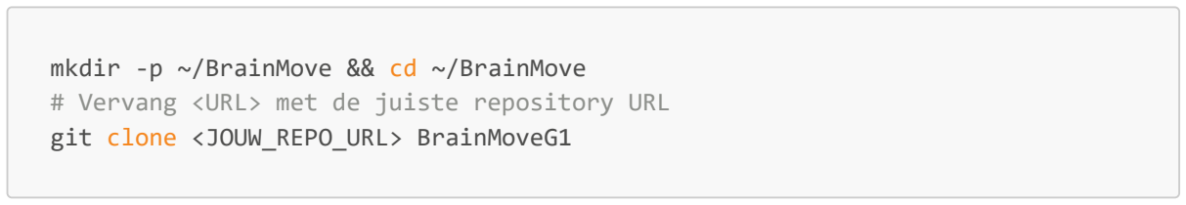
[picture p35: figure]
mkdir -p ~/BrainMove && cd ~/BrainMove; git clone <JOUW_REPO_URL> BrainMoveG1

# Vervang <URL> met de juiste repository URL

2. Hotspot Instellen: Controleer met ip link welke interface je dongle is (meestal wlan1 bij RPi5).

sudo raspi-config nonint do_wifi_country BE

# Hotspot aanmaken

sudo nmcli con add type wifi ifname wlan1 con-name "BrainMoveG1" autoconnect yes ssid "BrainMoveG1" mode ap ipv4.method shared wifi-sec.key-mgmt wpa-psk wifi-sec.psk "YOUR_SECURE_PASSWORD"

sudo nmcli connection up "BrainMoveG1"

3. Controleer hotspot status:
nmcli connection show --active | grep BrainMoveG1

## Fase 7: Backend Installatie (met venv)

Doel: Virtuele omgeving opzetten en dependencies installeren.

1. Ga naar de map en maak de omgeving:

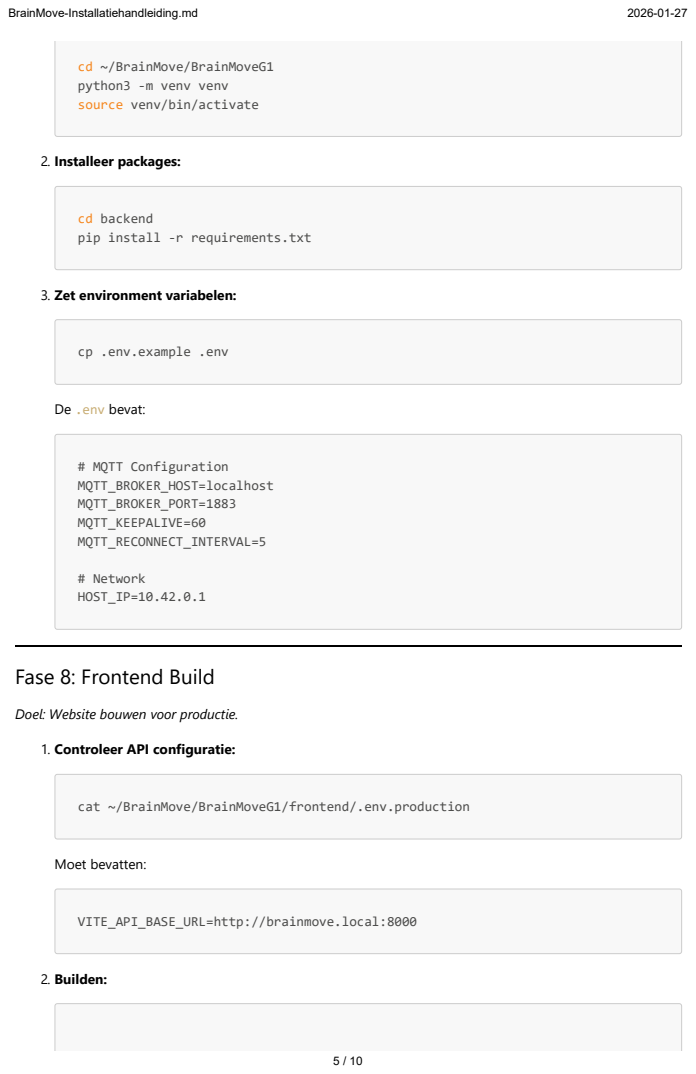
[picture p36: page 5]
2. Installeer packages:; # MQTT Configuration MQTT_BROKER_HOST=localhost MQTT_BROKER_PORT=1883 MQTT_KEEPALIVE=60 MQTT_RECONNECT_INTERVAL=5; # Network HOST_IP=10.42.0.1; Moet bevatten:; 2. Builden:

cd ~/BrainMove/BrainMoveG1
python3 -m venv venv
source venv/bin/activate

cd backend
pip install -r requirements.txt

3. Zet environment variabelen:

cp .env.example .env

De .env bevat:

Fase 8: Frontend Build

Doel: Website bouwen voor productie.

1. Controleer API configuratie:

cat ~/BrainMove/BrainMoveG1/frontend/.env.production

VITE_API_BASE_URL=http://brainmove.local:8000

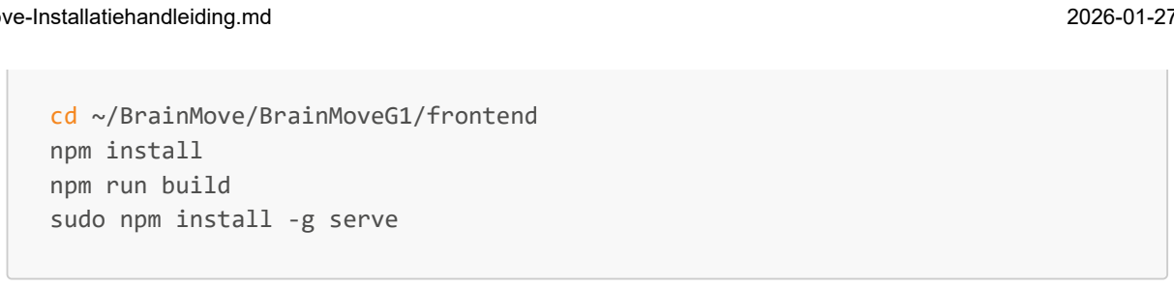
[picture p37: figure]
cd ~/BrainMove/BrainMoveG1/frontend npm install npm run build sudo npm install -g serve

## Fase 9: Systemd Services (Autostart)

Doel: Alles automatisch laten starten bij boot.

1. Backend Service:

[Unit]
Description=BrainMove Backend After=network.target mosquitto.service Wants=mosquitto.service

[Service]
User=bmajm
WorkingDirectory=/home/bmajm/BrainMove/BrainMoveG1/backend Environment="PYTHONPATH=/home/bmajm/BrainMove/BrainMoveG1/backend:/home/bmaj m/BrainMove/BrainMoveG1/backend/src" ExecStart=/home/bmajm/BrainMove/BrainMoveG1/venv/bin/uvicorn src.main:app --host 0.0.0.0 --port 8000
Restart=always
RestartSec=5

[Install]
WantedBy=multi-user.target
2. Frontend Service:

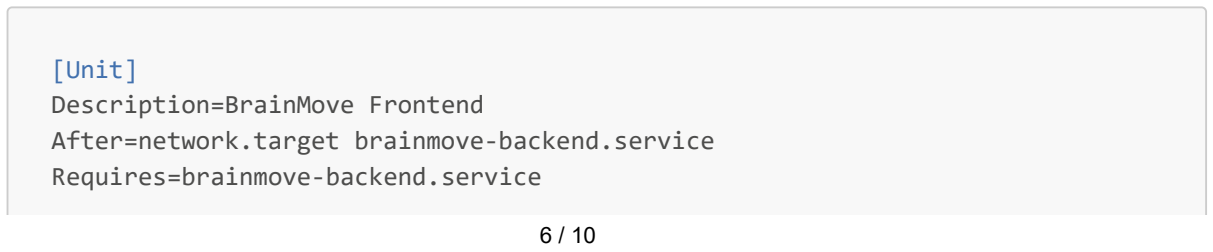
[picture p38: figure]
[Unit] Description=BrainMove Frontend After=network.target brainmove-backend.service Requires=brainmove-backend.service

[Service]
User=bmajm
WorkingDirectory=/home/bmajm/BrainMove/BrainMoveG1/frontend ExecStart=/usr/bin/npx serve -s dist -l 3000 Restart=always
RestartSec=10

[Install]
WantedBy=multi-user.target
3. Services activeren en starten:

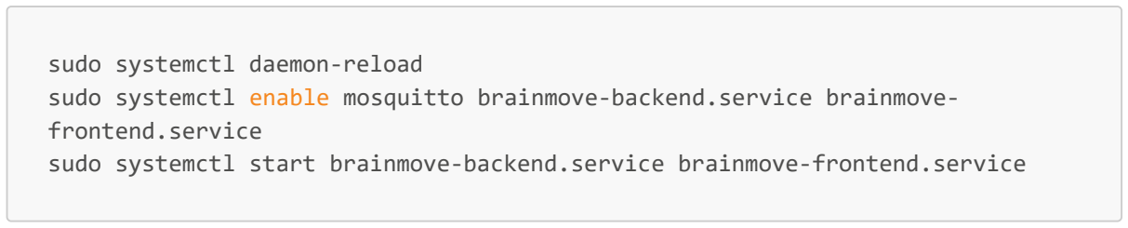
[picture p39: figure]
sudo systemctl daemon-reload; frontend.service sudo systemctl start brainmove-backend.service brainmove-frontend.service

sudo systemctl enable mosquitto brainmove-backend.service brainmove-

4. Status controleren:

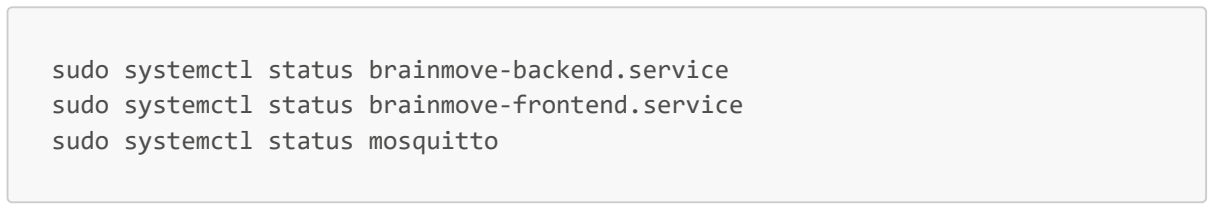
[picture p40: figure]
sudo systemctl status brainmove-backend.service sudo systemctl status brainmove-frontend.service sudo systemctl status mosquitto

## Fase 10: ESP32 Flashen

Doel: ESP32 apparaten programmeren met MQTT firmware.

De ESP32 firmware staat in esp32/brainmove_mqtt/brainmove_mqtt.ino.

Belangrijke instellingen in de code:

// WiFi credentials
const char* WIFI_SSID = "BrainMoveG1"; const char* WIFI_PASSWORD = "bmSecure5!";

// MQTT broker (Raspberry Pi)
const char* MQTT_HOST = "brainmove.local";
const int MQTT_PORT = 1883;

// Device color (uniek per ESP32)
const char* DEVICE_COLOR = "rood"; // of: blauw, geel, groen

Flash instructies:

## Fase 11: Custom Domein Instellen (Optioneel)

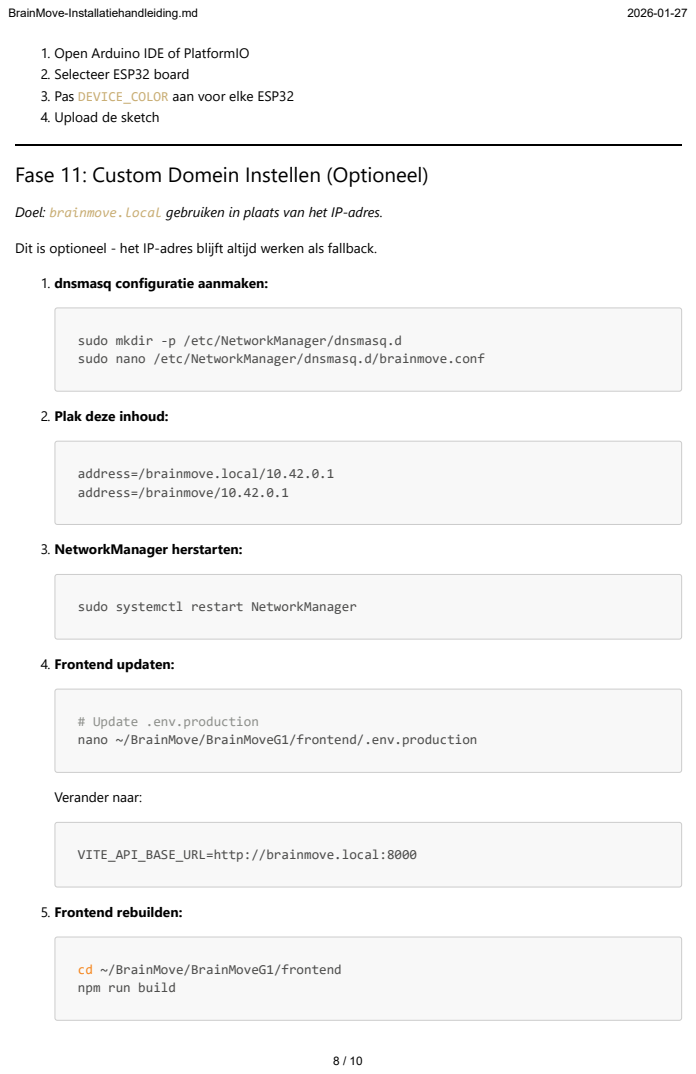
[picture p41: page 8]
3. NetworkManager herstarten:; 4. Frontend updaten:; Verander naar:; 5. Frontend rebuilden:

1. Open Arduino IDE of PlatformIO
2. Selecteer ESP32 board
3. Pas DEVICE_COLOR aan voor elke ESP32
4. Upload de sketch

Doel: brainmove.local gebruiken in plaats van het IP-adres.

Dit is optioneel - het IP-adres blijft altijd werken als fallback.

1. dnsmasq configuratie aanmaken:

sudo mkdir -p /etc/NetworkManager/dnsmasq.d
sudo nano /etc/NetworkManager/dnsmasq.d/brainmove.conf

2. Plak deze inhoud:

address=/brainmove.local/10.42.0.1
address=/brainmove/10.42.0.1

sudo systemctl restart NetworkManager

# Update .env.production
nano ~/BrainMove/BrainMoveG1/frontend/.env.production

VITE_API_BASE_URL=http://brainmove.local:8000

cd ~/BrainMove/BrainMoveG1/frontend
npm run build

6. Services herstarten:

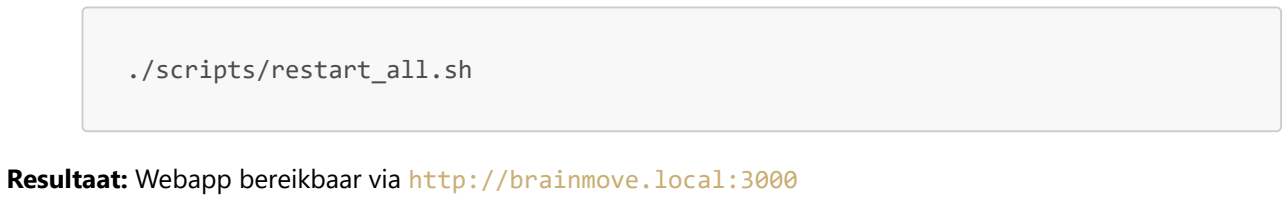
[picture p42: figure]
./scripts/restart_all.sh; Resultaat: Webapp bereikbaar via http://brainmove.local:3000

Voor uitgebreide troubleshooting, zie dnsmasq-setup-guide.md

## Gebruikers Toegang (QR Codes)

Print deze twee QR-codes uit voor op het apparaat:

1. Sticker 1: "Verbind met WiFi"

Code: WIFI:T:WPA;S:BrainMoveG1;P:bmSecure5!;;

2. Sticker 2: "Speel het spel"

Code: http://brainmove.local:3000

## Troubleshooting

## Backend start niet

# Bekijk logs

sudo journalctl -u brainmove-backend.service -f

# Test handmatig

cd ~/BrainMove/BrainMoveG1/backend
source ../venv/bin/activate
uvicorn src.main:app --host 0.0.0.0 --port 8000

## ESP32 verbindt niet met MQTT

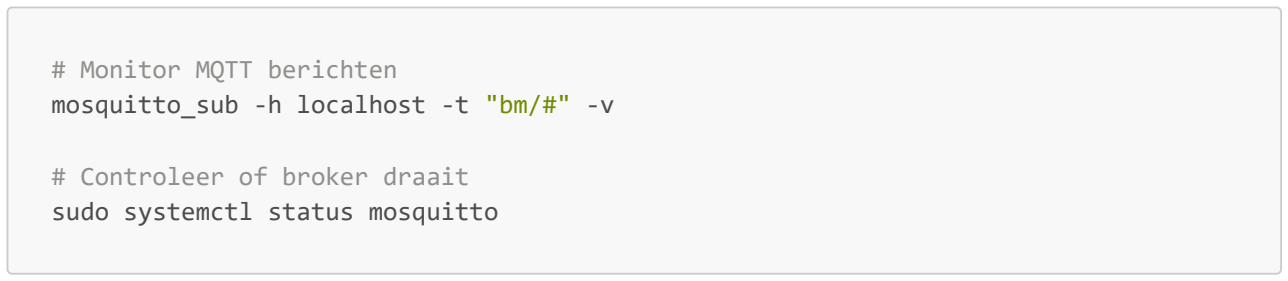
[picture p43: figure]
# Monitor MQTT berichten mosquitto_sub -h localhost -t "bm/#" -v; # Controleer of broker draait sudo systemctl status mosquitto

## Frontend laadt niet

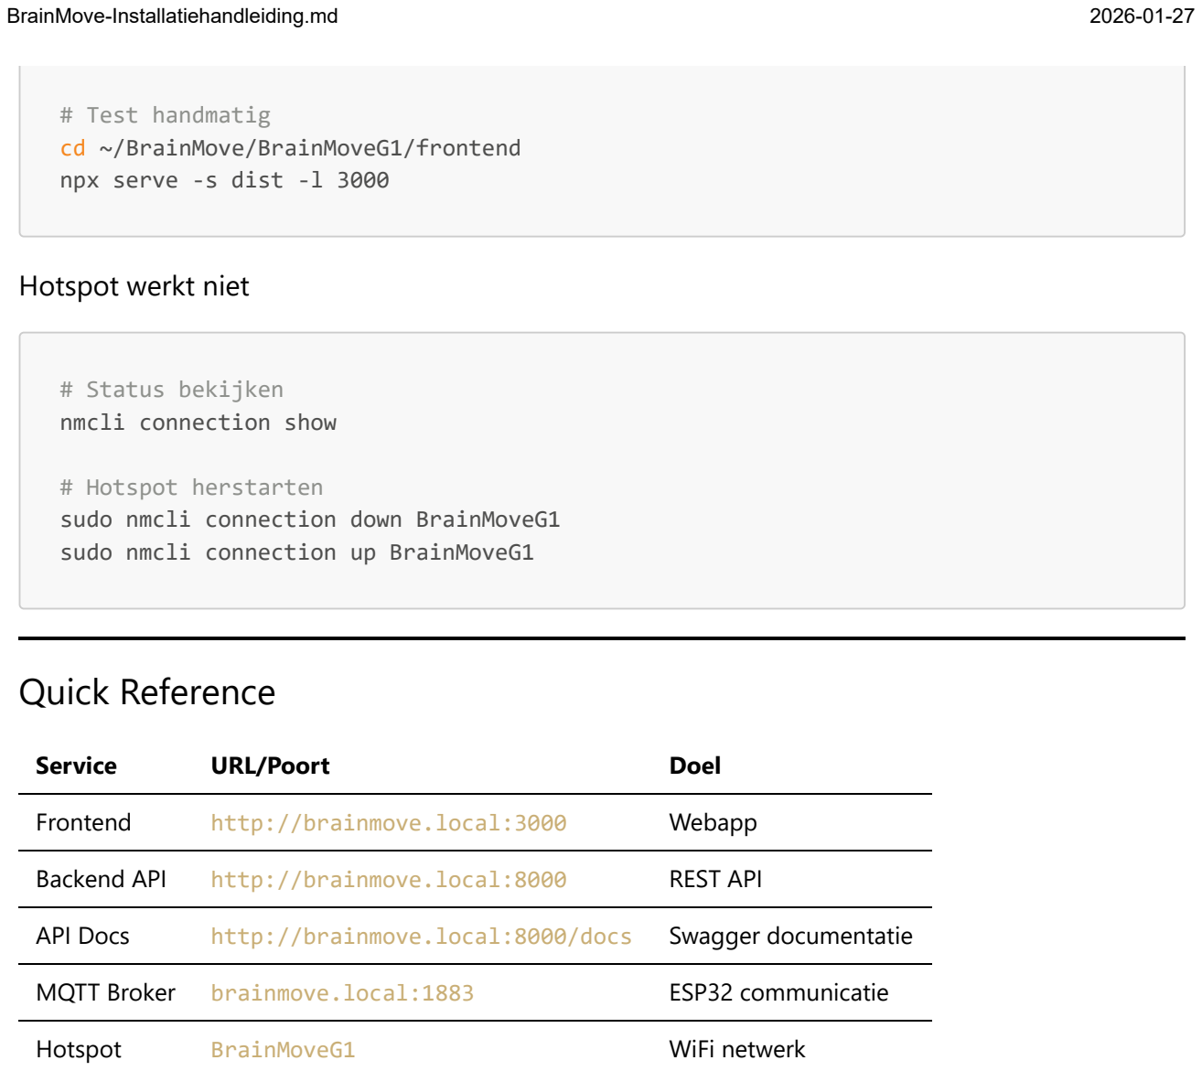
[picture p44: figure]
# Test handmatig cd ~/BrainMove/BrainMoveG1/frontend npx serve -s dist -l 3000; Hotspot werkt niet; # Status bekijken nmcli connection show; # Hotspot herstarten sudo nmcli connection down BrainMoveG1 sudo nmcli connection up BrainMoveG1; Quick Reference; Service; URL/Poort; Doel; Frontend; http://brainmove.local:3000; Webapp; Backend API; http://brainmove.local:8000; REST API; API Docs; http://brainmove.local:8000/docs; Swagger documentatie; MQTT Broker brainmove.local:1883; ESP32 communicatie; Hotspot; BrainMoveG1; WiFi netwerk

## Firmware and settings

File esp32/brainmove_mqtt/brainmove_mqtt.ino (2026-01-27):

#include <Arduino.h>
#include <WiFi.h>
#include <PubSubClient.h>
#include <Wire.h>
#include <VL53L0X.h>

#define DEVICE_COLOR "geel"

const char* WIFI_SSID = "BrainMoveG1";
const char* WIFI_PASSWORD = "bmSecure1998";

const char* MQTT_BROKER = "10.42.0.1";
const int MQTT_PORT = 1883;
const int MQTT_KEEPALIVE_DURATION = 5; 

const int PIN_BATTERIJ_ADC = 2;
const int PIN_KNOP = 3;
const int PIN_TOF_XSHUT = 4;
const int PIN_ZOEMER = 5;

const int PIN_I2C_SDA = 6;
const int PIN_I2C_SCL = 7;

const uint16_t TOF_DETECTIE_MIN_MM = 50;
const uint16_t TOF_DETECTIE_MAX_MM = 600;
const uint16_t TOF_POLL_INTERVAL_MS = 35;
const uint16_t TOF_DETECTIE_AFKOELING_MS = 300;

const float BATTERIJ_VOL_SPANNING = 4.2f;
const float BATTERIJ_LEEG_SPANNING = 3.0f;
const float BATTERIJ_SPANNINGSDELER = 2.0f;

const unsigned long BATTERIJ_UPDATE_INTERVAL = 30000;
const uint8_t BATTERIJ_KRITIEK_PERCENTAGE = 5;

const unsigned long GLOBALE_INACTIEF_TIMEOUT_MS = (10UL * 60UL * 1000UL);
const unsigned long KNOP_DEBOUNCE_MS = 150;
const unsigned long VERBINDING_PIEP_INTERVAL_MS = 10000;

const int ZOEMER_KANAAL = 0;
const int ZOEMER_RESOLUTIE = 8;
const int ZOEMER_FREQ_STANDAARD = 2000;

WiFiClient wifiClient;
PubSubClient mqttClient(wifiClient);
VL53L0X tofSensor;

String topic_detect, topic_battery, topic_status, topic_cmd, topic_cmd_all;

bool isPolling = false;
bool isCorrectTarget = false;
bool tofGeinitialiseerd = false;
volatile bool knopIngedrukt = false;

unsigned long laatsteTofPollTijd = 0;
unsigned long laatsteDetectieTijd = 0;
unsigned long laatsteActiviteitTijd = 0;
unsigned long laatsteBatterijUpdateTijd = 0;
unsigned long laatsteKnopDrukTijd = 0;

void IRAM_ATTR knopISR() { knopIngedrukt = true; }
void verbindGeforceerd();
void mqttCallback(char* topic, byte* payload, unsigned int length);
void initHardware();
void verwerkKnopDruk();
void verwerkKnopTijdensVerbinden();
void verwerkKnopHold(bool tijdensVerbinden);
void verwerkToF();
uint8_t leesBatterijPercentage();
void speelCorrectGeluid();
void speelIncorrectGeluid();
void speelVerbindingGeluid();
void speelOntwaakGeluid();
void speelVerbindingZoekGeluid();
void speelBatterijLeegGeluid();
void zoemerToon(uint32_t freq, uint32_t duur);
void zoemerUit();
void gaaDiepeSlaap();
void controleerKritiekeBatterij();

void setup() {
  Serial.begin(115200);
  delay(3000);
  
  esp_sleep_wakeup_cause_t ontwaakOorzaak = esp_sleep_get_wakeup_cause();
  initHardware();
  if (ontwaakOorzaak == ESP_SLEEP_WAKEUP_GPIO) speelOntwaakGeluid();
  
  topic_detect = String("bm/") + DEVICE_COLOR + "/detect";
  topic_battery = String("bm/") + DEVICE_COLOR + "/battery";
  topic_status = String("bm/") + DEVICE_COLOR + "/status";
  topic_cmd = String("bm/") + DEVICE_COLOR + "/cmd";
  topic_cmd_all = "bm/all/cmd";
  
  mqttClient.setServer(MQTT_BROKER, MQTT_PORT);
  mqttClient.setCallback(mqttCallback);
  mqttClient.setKeepAlive(MQTT_KEEPALIVE_DURATION);
  
  laatsteActiviteitTijd = millis();

  uint8_t batterijPercentageBoot = leesBatterijPercentage();
    Serial.print("Battery % on boot: ");
    Serial.println(batterijPercentageBoot);
}

void loop() {
  if (WiFi.status() != WL_CONNECTED || !mqttClient.connected()) {
    verbindGeforceerd(); 
  }

  mqttClient.loop();
  verwerkKnopDruk();

  if (isPolling) {
    verwerkToF();
  }

  if (millis() - laatsteBatterijUpdateTijd >= BATTERIJ_UPDATE_INTERVAL) {
    laatsteBatterijUpdateTijd = millis();
    uint8_t batterijPercentage = leesBatterijPercentage();
    String payload = String(batterijPercentage);
    mqttClient.publish(topic_battery.c_str(), payload.c_str(), false);

    Serial.print("Battery % sent: ");
    Serial.println(batterijPercentage);
  }


  yield();
}

void verbindGeforceerd() {
  static unsigned long verbindingStartTijd = 0;
  static unsigned long laatstePiepTijd = 0;

  if (verbindingStartTijd == 0) {
    verbindingStartTijd = millis();
    laatstePiepTijd = 0;
  }

  Serial.println("Verbinding verloren...");
  zoemerUit();
  isPolling = false;

  if (WiFi.status() != WL_CONNECTED) {
    Serial.print("WiFi: "); Serial.println(WIFI_SSID);
    WiFi.disconnect();
    WiFi.mode(WIFI_STA);
    WiFi.setSleep(true);
    WiFi.begin(WIFI_SSID, WIFI_PASSWORD);

    while (WiFi.status() != WL_CONNECTED) {
      if (knopIngedrukt) {
        knopIngedrukt = false;
        verwerkKnopTijdensVerbinden();
      }
      if (millis() - verbindingStartTijd > GLOBALE_INACTIEF_TIMEOUT_MS) {
        Serial.println("\nWiFi timeout - ga slapen...");
        gaaDiepeSlaap();
      }
      if (millis() - laatstePiepTijd >= VERBINDING_PIEP_INTERVAL_MS) {
        speelVerbindingZoekGeluid();
        laatstePiepTijd = millis();
      }
      delay(500); Serial.print(".");
    }
    Serial.println(" WiFi OK.");
  }

  while (!mqttClient.connected()) {
    if (knopIngedrukt) {
      knopIngedrukt = false;
      verwerkKnopTijdensVerbinden();
    }
    if (millis() - verbindingStartTijd > GLOBALE_INACTIEF_TIMEOUT_MS) {
      Serial.println("MQTT timeout - ga slapen...");
      gaaDiepeSlaap();
    }
    if (millis() - laatstePiepTijd >= VERBINDING_PIEP_INTERVAL_MS) {
      speelVerbindingZoekGeluid();
      laatstePiepTijd = millis();
    }

    if (WiFi.status() != WL_CONNECTED) return;

    String clientId = String("BM-") + DEVICE_COLOR + "-" + String(ESP.getEfuseMac(), HEX);

    if (mqttClient.connect(clientId.c_str(), topic_status.c_str(), 1, true, "offline")) {
      Serial.println("MQTT OK!");

      mqttClient.subscribe(topic_cmd.c_str());
      mqttClient.subscribe(topic_cmd_all.c_str());

      mqttClient.publish(topic_status.c_str(), "online", true);

      uint8_t batterijPercentage = leesBatterijPercentage();
      String battPayload = String(batterijPercentage);
      mqttClient.publish(topic_battery.c_str(), battPayload.c_str(), false);

      Serial.print("Battery % sent: ");
      Serial.println(batterijPercentage);

      laatsteBatterijUpdateTijd = millis();
      speelVerbindingGeluid();
      laatsteActiviteitTijd = millis();

      verbindingStartTijd = 0;

    } else {
      Serial.print("MQTT Fail rc="); Serial.println(mqttClient.state());
      delay(2000);
    }
  }
}

void mqttCallback(char* topic, byte* payload, unsigned int length) {
  String message = "";
  for (unsigned int i = 0; i < length; i++) message += (char)payload[i];
  laatsteActiviteitTijd = millis();
  if (message == "start") {
    isPolling = true;
    WiFi.setSleep(false);
  }
  else if (message == "stop") {
    isPolling = false;
    WiFi.setSleep(true);
  }
  else if (message == "correct") isCorrectTarget = true;
  else if (message == "incorrect") isCorrectTarget = false;
  else if (message == "sleep") {
    zoemerToon(800, 100); delay(50); zoemerToon(500, 150);
    gaaDiepeSlaap();
  }
  else if (message == "sound_ok") speelCorrectGeluid();
  else if (message == "sound_fail") speelIncorrectGeluid();
}

void initHardware() {
  pinMode(PIN_KNOP, INPUT_PULLUP);
  attachInterrupt(digitalPinToInterrupt(PIN_KNOP), knopISR, FALLING);
  ledcAttach(PIN_ZOEMER, ZOEMER_FREQ_STANDAARD, ZOEMER_RESOLUTIE);
  ledcWrite(PIN_ZOEMER, 0);
  analogReadResolution(12);
  analogSetAttenuation(ADC_11db);

  pinMode(PIN_TOF_XSHUT, OUTPUT);
  digitalWrite(PIN_TOF_XSHUT, LOW);
  delay(10);
  digitalWrite(PIN_TOF_XSHUT, HIGH);
  delay(10);

  Wire.begin(PIN_I2C_SDA, PIN_I2C_SCL);
  Wire.setClock(400000);
  tofSensor.setTimeout(500);
  if (!tofSensor.init()) {
    Serial.println("FOUT: Geen sensor!");
    tofGeinitialiseerd = false;
  } else {
    tofSensor.setMeasurementTimingBudget(33000);
    tofSensor.setSignalRateLimit(0.5);
    tofSensor.startContinuous();
    tofGeinitialiseerd = true;
  }
}

void verwerkKnopHold(bool tijdensVerbinden) {
    const unsigned long HOLD_RESTART_MS = 1500;
    const unsigned long HOLD_CANCEL_MS = 3000;

    unsigned long pressStart = millis();
    bool restartBeeped = false;

    while (digitalRead(PIN_KNOP) == LOW) {
        unsigned long holdTime = millis() - pressStart;

        if (!restartBeeped && holdTime >= HOLD_RESTART_MS) {
            zoemerToon(1500, 80);
            restartBeeped = true;
        }

        if (holdTime >= HOLD_CANCEL_MS + 1000) break;

        delay(10);
    }

    unsigned long holdDuration = millis() - pressStart;

    if (holdDuration >= HOLD_CANCEL_MS) {
        Serial.println("Knop te lang ingedrukt - geannuleerd");
        zoemerToon(300, 200);

        while (digitalRead(PIN_KNOP) == LOW) delay(10);
        delay(500);
        knopIngedrukt = false;
        return;

    } else if (holdDuration >= HOLD_RESTART_MS) {
        Serial.println("Knop lang ingedrukt - herstart ESP...");
        zoemerToon(1000, 100); delay(50); zoemerToon(1500, 100);
        if (!tijdensVerbinden && mqttClient.connected()) {
            mqttClient.publish(topic_status.c_str(), "restarting", true);
            mqttClient.disconnect();
        }
        delay(100);
        ESP.restart();

    } else {
        Serial.println("Knop kort ingedrukt - ga slapen...");
        zoemerToon(800, 100); delay(50); zoemerToon(500, 150);
        gaaDiepeSlaap();
    }
}

void verwerkKnopDruk() {
    if (!knopIngedrukt) return;
    if (millis() - laatsteKnopDrukTijd < KNOP_DEBOUNCE_MS) { knopIngedrukt = false; return; }
    knopIngedrukt = false;
    laatsteKnopDrukTijd = millis();
    laatsteActiviteitTijd = millis();

    verwerkKnopHold(false);
}

void verwerkKnopTijdensVerbinden() {
    verwerkKnopHold(true);
}

void verwerkToF() {
    if (!tofGeinitialiseerd) return;
    if (millis() - laatsteTofPollTijd >= TOF_POLL_INTERVAL_MS) {
        laatsteTofPollTijd = millis();
        uint16_t afstand = tofSensor.readRangeContinuousMillimeters();
        if (tofSensor.timeoutOccurred()) return; 
        bool geldigeDetectie = (afstand > TOF_DETECTIE_MIN_MM && afstand < TOF_DETECTIE_MAX_MM);
        if (geldigeDetectie && (millis() - laatsteDetectieTijd >= TOF_DETECTIE_AFKOELING_MS)) {
            if (isCorrectTarget) speelCorrectGeluid(); else speelIncorrectGeluid();
            String payload = String(afstand);
            mqttClient.publish(topic_detect.c_str(), payload.c_str(), false);
            laatsteDetectieTijd = millis();
            laatsteActiviteitTijd = millis();
        }
    }
}

uint8_t leesBatterijPercentage() {
    long totaal = 0;
    for (int i = 0; i < 16; i++) {
        totaal += analogRead(PIN_BATTERIJ_ADC);
        delayMicroseconds(500);
    }
    int adcWaarde = totaal / 16;

    float spanning = (adcWaarde / 4095.0f) * 3.3f * BATTERIJ_SPANNINGSDELER;

    const float lipoTabel[][2] = {
        {4.20f, 100.0f},
        {4.10f,  90.0f},
        {4.00f,  80.0f},
        {3.90f,  70.0f},
        {3.80f,  55.0f},
        {3.70f,  40.0f},
        {3.60f,  25.0f},
        {3.50f,  15.0f},
        {3.40f,   8.0f},
        {3.30f,   4.0f},
        {3.00f,   0.0f}
    };
    const int tabelGrootte = sizeof(lipoTabel) / sizeof(lipoTabel[0]);

    if (spanning >= lipoTabel[0][0]) return 100;
    if (spanning <= lipoTabel[tabelGrootte - 1][0]) return 0;

    for (int i = 0; i < tabelGrootte - 1; i++) {
        if (spanning >= lipoTabel[i + 1][0]) {
            float spanHoog = lipoTabel[i][0];
            float spanLaag = lipoTabel[i + 1][0];
            float percHoog = lipoTabel[i][1];
            float percLaag = lipoTabel[i + 1][1];
            float percentage = percLaag + (spanning - spanLaag) / (spanHoog - spanLaag) * (percHoog - percLaag);
            return (uint8_t)percentage;
        }
    }
    return 0;
}

void zoemerToon(uint32_t freq, uint32_t duur) {
    ledcChangeFrequency(PIN_ZOEMER, freq, ZOEMER_RESOLUTIE);
    ledcWrite(PIN_ZOEMER, 127); delay(duur); zoemerUit();
}
void zoemerUit() { ledcWrite(PIN_ZOEMER, 0); }
void speelCorrectGeluid() { zoemerToon(1000, 100); delay(50); zoemerToon(1500, 100); delay(50); zoemerToon(2000, 150); }
void speelIncorrectGeluid() { zoemerToon(400, 150); delay(50); zoemerToon(300, 150); delay(50); zoemerToon(200, 200); }
void speelVerbindingGeluid() { zoemerToon(800, 100); delay(50); zoemerToon(1200, 150); }
void speelOntwaakGeluid() { zoemerToon(500, 100); delay(30); zoemerToon(800, 100); delay(30); zoemerToon(1200, 120); }
void speelVerbindingZoekGeluid() { zoemerToon(600, 80); }
void speelBatterijLeegGeluid() { zoemerToon(300, 200); delay(100); zoemerToon(200, 300); }

void gaaDiepeSlaap() {
    if (mqttClient.connected()) {
        mqttClient.publish(topic_status.c_str(), "sleeping", true);
        mqttClient.disconnect();
    }
    delay(100); zoemerUit();
    if (tofGeinitialiseerd) tofSensor.stopContinuous();

    digitalWrite(PIN_TOF_XSHUT, LOW);

    esp_deep_sleep_enable_gpio_wakeup(BIT(PIN_KNOP), ESP_GPIO_WAKEUP_GPIO_LOW);
    esp_deep_sleep_start();
}

void controleerKritiekeBatterij() {
    uint8_t batterij = leesBatterijPercentage();
    if (batterij <= BATTERIJ_KRITIEK_PERCENTAGE) {
        Serial.println("Kritieke batterij - ga slapen...");
        speelBatterijLeegGeluid();
        gaaDiepeSlaap();
    }
}

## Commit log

2026-01-06 Remove obsolete firmware and configuration files for ESP32 and Raspberry Pi 5
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2026-01-07 Refactor ESP32 Test Server to use BLE for device communication and enhance message handling
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2026-01-07 Refactor BLE connection test for ESP32-C3: optimize for Raspberry Pi connection, update comments, and remove LED functionality
2026-01-10 Refactor code structure for improved readability and maintainability
    [cone-base4.stl, cone.stl]
2026-01-11 feat: Add device management and BLE functionality for BrainMove devices
    - Implement DeviceManager class for managing ESP32 devices.
    - Create ESP32Device class for handling BLE communication and events.
    - Add configuration management via environment variables in config_env.py.
    - Develop a command-line interface in esp-use.py for device interaction.
    - Introduce scanning, connecting, polling, and event monitoring features.
    - Set up requirements.txt for necessary dependencies.
    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
    [cone-base4.stl, cone.stl]
2026-01-11 feat: Update DEVICE_ID to 3 for correct device identification
2026-01-11 feat: Update DEVICE_ID definitions and enhance print statements for clarity
    [hub-top.stl]
2026-01-12 Refactor ESP32 and DeviceManager for improved health monitoring and configuration
    - Adjusted button debounce time and TOF polling interval in ESP32 firmware.
    - Introduced TOF detection thresholds for better object detection accuracy.
    - Enhanced DeviceManager to load trusted devices and configuration from environment variables.
    - Added health monitoring methods in ESP32Device to check device connectivity based on keepalive messages.
    - Removed config_env.py and integrated its functionality directly into DeviceManager.
    - Updated esp-use.py to utilize the new DeviceManager structure and callbacks for device management.
2026-01-12 feat: Remove outdated documentation files and add a comprehensive quick start guide for DeviceManager and ESP32Device
2026-01-12 feat: Update .gitignore to include esp32-backend and *.code-workspace refactor: Clean up QUICK_START.md by removing unnecessary callback explanations and examples delete: Remove obsolete program.ino 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
2026-01-12 feat: Enhance esp-use.py menu with disconnect option and improve device management during scanning
2026-01-12 fix: Correct device MAC reference to address in trusted device checks
2026-01-12 feat: Update 3D models for cone components in drawings and schematics
    [cone-base.3mf, cone-base.stl, cone-top.3mf]
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2026-01-13 feat: Refactor DeviceManager initialization and enhance ESP32Device reconnection settings
    [cone-base.3mf]
2026-01-13 feat: implement game detail view with filters and leaderboard, add game listing page
2026-01-13 feat: Update device manager and ESP32 device handling with Dutch translations and improved variable mappings
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2026-01-13 feat: Rename address variable to mac_address in ESP32Device and update related logging for clarity
2026-01-14 feat: enhance game detail view with username validation, color selection, and improved button styling
2026-01-14 feat: Update logging levels to INFO for better visibility and enhance device detection logic in DeviceManager and ESP32Device classes
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2026-01-14 feat: Add esp32-backend.ino file for hardware integration and BLE functionality; update .gitignore to include workspace files
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2026-01-15 feat: Add DeviceManager and ESP32Device classes for managing BLE devices; implement colorgame logic and API endpoints
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2026-01-15 feat: add ButtonsNext component for circular navigation with progress indicator
    - Implemented ButtonsNext.vue with customizable progress, size, color, and disabled state.
    - Added SVG circles for visual progress representation.
    - Integrated router-link for navigation functionality.
    feat: create CardPotjes component to display pot status
    - Developed CardPotjes.vue to show pot image and online/offline status.
    - Utilized props for dynamic image sourcing and status indication.
    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
2026-01-15 Refactor code structure for improved readability and maintainability; remove redundant code blocks and optimize function calls.
    [cone-base-v2 1.3mf, cone-base.3mf, cone-base.stl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]
2026-01-15 feat: add game detail and game play views with socket integration
    - Implemented AppDetail.vue for game settings and user input validation.
    - Created AppGame.vue for real-time game interaction with socket communication.
    - Added AppGames.vue to display a list of available games.
    - Developed onboarding views (OnboardingSetup.vue, OnboardingStart.vue, OnboardingWarning.vue) for user guidance.
    - Introduced results overview (ResultatenOverzicht.vue) and congratulatory page (ResultatenProficiat.vue) after game completion.
    - Integrated TypeScript configuration files for improved type checking and linting.
    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
2026-01-16 fix: correct prop name from 'to' to 'url' in ButtonsPrimary component in ResultatenProficiat.vue
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2026-01-20 Update socket connection URL to use the correct address
2026-01-20 Update socket connection URL to use the correct IP address
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2026-01-20 Adjust socket connection settings for improved stability and update API base URL for production
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2026-01-21 feat: Implement MQTT client to replace BLE communication
    - Added MQTTDeviceManager class for managing ESP32 devices via MQTT.
    - Updated requirements.txt to include aiomqtt and marked BLE dependencies as deprecated.
    - Created test script for MQTT functionality to verify client operations.
    - Documented MQTT backend implementation status and conversion plan.
    - Updated main application to integrate MQTT client and remove BLE dependencies.
    - Added environment configuration for MQTT settings.
2026-01-21 Add Raspberry Pi setup guide and ESP32 MQTT firmware
    - Created RPI_SETUP_GUIDE.md for detailed setup instructions of the Raspberry Pi with Mosquitto MQTT Broker and configuration steps.
    - Added ESP32 firmware (brainmove_mqtt.ino) for MQTT communication, including sensor detection, battery status reporting, and command handling.
    [brainmove_mqtt.ino]
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2026-01-21 feat: Update device color and optimize MQTT connection logic for improved stability
    [brainmove_mqtt.ino]
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2026-01-21 fix: Remove caching of games data in sessionStorage to ensure fresh data fetch on component mount
2026-01-22 fix: Set static progress value for ButtonsNext component in onboarding setup
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2026-01-22 feat: Implement onboarding route handling and disable device monitoring during onboarding fix: Adjust AppPopup image width for better display feat: Add turnOff function to handle device shutdown in A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
2026-01-22 feat: Add Number Match game component and enhance error handling in device shutdown
2026-01-23 feat: add DetailPopup component for error notifications
    - Implemented a new DetailPopup component using Vue 3's Composition API.
    - The popup displays a title and message, with a close button for user interaction.
    - Added styling for the popup overlay and content for better user experience.
    - Integrated TriangleAlert icon from lucide-vue-next for visual indication.
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2026-01-23 feat: add Falling Colors game component with socket integration and animations
    - Implemented the main game logic for Falling Colors in AppGameFallingColors.vue.
    - Added socket communication for game events including color falling, percentage updates, and game end.
    - Introduced visual elements such as falling orbs, explosion effects, and countdown timer.
    - Created reusable components for game header, countdown, and progress tracking.
    - Enhanced user experience with audio feedback and responsive design adjustments.
    - Added AppPasswordConfirm.vue for password confirmation with loading state and error handling.
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2026-01-23 fix: update device color to yellow and adjust TOF polling interval and timing budget
    [brainmove_mqtt.ino]
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2026-01-25 fix: update battery life estimates in documentation and code
    [brainmove_mqtt.ino]
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2026-01-26 feat: enhance styling for IntroOverlay and ensure scroll position resets on AppDetail mount
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2026-01-26 fix: update DEVICE_COLOR to "blauw" and adjust TOF sensor parameters for improved performance
    [brainmove_mqtt.ino]
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2026-01-27 fix: remove filtering of game with ID 5 from game list retrieval
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2026-01-27 fix: remove reconnectionAttempts from socket configuration
